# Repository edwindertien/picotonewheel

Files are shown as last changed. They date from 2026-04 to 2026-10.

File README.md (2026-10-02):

# Pico Tonewheel Organ

A Hammond-style tonewheel organ sound module built on a **Raspberry Pi Pico 2 (RP2350)**: nine-drawbar polyphonic tonewheel synthesis, percussion and key click, and an effects chain with **overdrive, vibrato, chorus and a stereo Leslie rotary-speaker simulation**. It plays from a home-built keyboard unit, from any USB MIDI controller plugged into its USB-A host socket, or from a computer. A small colour LCD shows the drawbars and effect settings.

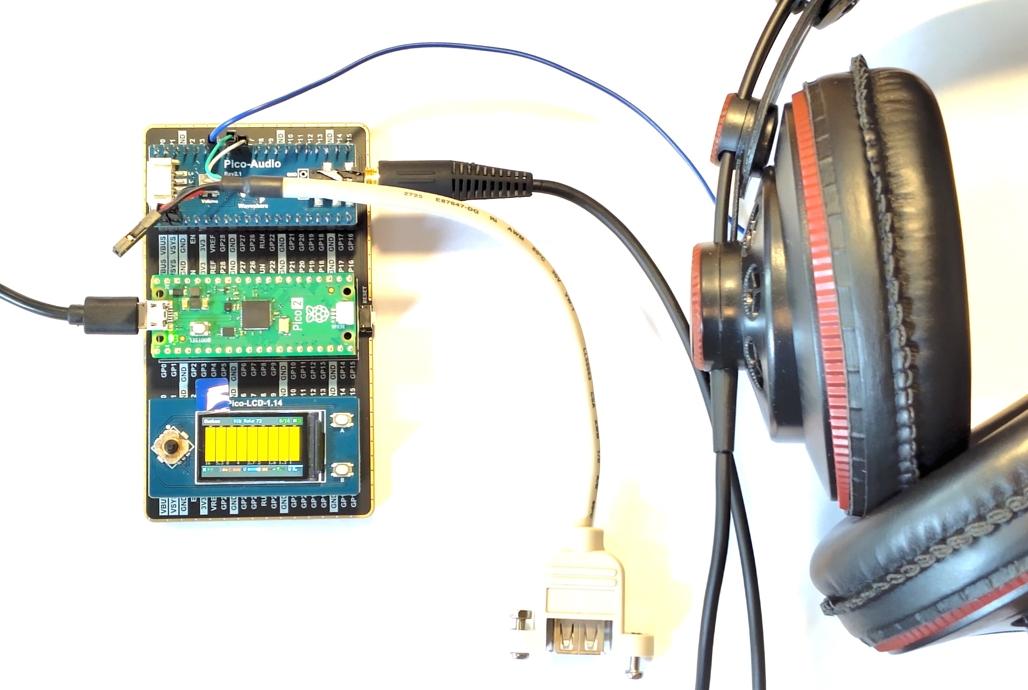
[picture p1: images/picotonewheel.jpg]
the module


> **TODO (author):** add 2–3 photos to `images/` — the finished instrument, the inside of the case, the front panel — and reference them here.

**Highlights**

- 16-note polyphony (9 partials per note) with Hammond drawbar footages, first-note-only percussion (2nd/3rd harmonic, fast/slow, soft/normal) and key click
- Overdrive: anti-aliased tube-style clipper with loudness-following makeup
- Vibrato (authentic ±0.25 semitone scanner depth), dual-quadrature chorus
- Leslie simulation: horn + drum rotors, Doppler, two microphones, **slow / stop / fast with realistic run-up and run-down**
- Three MIDI inputs merged: UART (keyboard unit), USB host (controllers), USB device (computer)
- A **load governor** that drops notes gracefully instead of letting the pitch fall or the DAC mute
- Everything controllable three ways: MIDI CC, joystick + LCD, serial console
- Runs from SRAM on core 1; I²S audio through a PIO state machine

## Contents

1. [The big picture](#1-the-big-picture)
2. [What you need](#2-what-you-need)
3. [Building the hardware](#3-building-the-hardware)
4. [Firmware: build, flash, first power-on](#4-firmware-build-flash-first-power-on)
5. [Playing it: controls](#5-playing-it-controls)
6. [How it works](#6-how-it-works)
7. [Tuning guide](#7-tuning-guide)
8. [Testing and verification status](#8-testing-and-verification-status)
9. [Troubleshooting](#9-troubleshooting)
10. [Limitations and roadmap](#10-limitations-and-roadmap)
11. [Repository layout, licence, credits](#11-repository-layout-licence-credits)

---

## 1. The big picture

system overview

The organ is two cooperating units:

| Unit | What it does | Where |
|---|---|---|
| **Keyboard & control unit** | Scans the keys, reads 16 analog controls (drawbars, pots, switches) and sends them as MIDI | companion project *pico MIDI keyboard* (RP2040 Pico) |
| **Tone generator** | Receives MIDI, synthesises and processes the sound, drives the DAC and the display | **this repository** (Pico 2) |

The tone generator accepts MIDI from **three sources at once** and treats them identically: the UART input (GP5, 31 250 baud — the keyboard unit), the USB-A host socket (one class-compliant USB MIDI device) and its native USB port (computer / DAW). Because everything is just MIDI, the sound module also works with nothing but a USB keyboard plugged in.

---

## 2. What you need

### 2.1 Tone generator (this repository)

| Qty | Part | Notes |
|-----|---|---|
| 1 | Raspberry Pi **Pico 2** (RP2350) | The build needs three PIO blocks and the Cortex-M33 FPU — a Pico 1 will not do |
| 1 | Waveshare **Pico-Audio** (Rev 2.1, CS4344 DAC) | stacks on the Pico; I²S pins are hard-wired on its PCB |
| 1 | Waveshare **Pico-LCD-1.14** (ST7789V 240×135, joystick, 2 buttons) | stacks on the Pico-Audio; pins hard-wired |
| 1 | USB-A socket (breakout or panel mount) | for the USB host input |
| 1 | 15 kΩ resistor | D+ pull-down — **required**, makes the Pico a USB host |
| 1 | Schottky diode (e.g. 1N5819) + 100 µF electrolytic + 100 nF ceramic | *recommended*: isolates power-hungry controllers (see [3.4](#34-power-and-noise)) |
| — | Hook-up wire, pin headers, USB cable for programming | |
| opt. | DIN-5 MIDI-in circuit (optocoupler 6N138 or similar) | feeds the same GP5 input; not part of the tested build |

> **TODO (author):** add supplier links / part numbers, the header arrangement used for the stack (or the expansion board mentioned below), power supply details (USB 5 V vs. VSYS) and the cost.
>
> The hardware note from the original README still applies: *the boards can be stacked, or used (for now) on an expansion board; a board combining MIDI-in and USB-host in is in the pipeline so the whole module can be a compact stack.*

### 2.2 Keyboard & control unit (companion project)

As built by the author (see the separate *pico MIDI keyboard* repository):

- Raspberry Pi Pico (RP2040), PlatformIO / earlephilhower core
- key matrix: 12 receive lines (GPIO0–11) and 16 send lines through two **74HC238** decoders (GPIO13/14/15 + 16); two selectable layouts — a double-row keyboard (two manuals) or velocity-sensing keys with make/break contacts
- **16 analog controls through a 4067 multiplexer** into ADC0 (GPIO26; mux select GPIO17/18/19/22): nine drawbars, three pots, three three-state switches, one Leslie switch
- MIDI out on UART TX (GPIO12 in the current firmware), 31 250 baud
- OLED + M5Stack encoder on I²C (GPIO20/21) for setup

> **TODO (author):** link the keyboard-unit repository, add its BOM, schematic and photos. Document the drawbar/pot/switch wiring (which mux channel is which CC).

### 2.3 Enclosure and panel

> **TODO (author) — everything needed to cut and assemble the case.** Suggested contents of a `hardware/` folder, each referenced from here:
>
> | File | Purpose |
> |------|---------|
> | `hardware/enclosure/*.svg` / `*.dxf` | laser-cut drawings, one file per material thickness |
> | `hardware/enclosure/README.md` | material (e.g. 3 mm birch ply / acrylic), kerf compensation used, assembly order, screws |
> | `hardware/panel/` | front-panel drawing with cut-outs: LCD window (Pico-LCD-1.14 active area), joystick + 2 buttons, USB-A socket, 3.5 mm audio jack, USB programming port access, MIDI in |
> | `hardware/bom.csv` | one machine-readable bill of materials |
> | `docs/photos/` | build photos in assembly order |
>
> A photo of the cut parts laid out, and one of the open case with the cabling, will save every builder an evening.

### 2.4 Tools

PlatformIO (VS Code extension or CLI), a soldering iron, a USB cable, and a serial terminal (the PlatformIO monitor works, 115 200 baud).

---

## 3. Building the hardware

### 3.1 The stack and the pins

```
[Pico-LCD-1.14]   ← top
[Pico-Audio]      ← middle   (pass-through header exposes all Pico pins)
[Pico 2]          ← bottom
```

GPIO map

Only **three connections are wired by hand**: GP5 (MIDI in), GP6/GP7 (USB host). Everything else is fixed by the two Waveshare boards, and there is **no conflict** between them.

| Function | GPIO |
|---|---|
| I²S: DIN / BCK / LRCK (Pico-Audio, hard-wired) | GP22 / GP26 / GP27 |
| LCD: DC, CS, SCK, MOSI, RST, backlight (SPI1) | GP8, GP9, GP10, GP11, GP12, GP13 |
| Joystick: UP, DOWN, LEFT, RIGHT, PRESS | GP2, GP18, GP16, GP20, GP3 |
| Buttons A, B | GP15, GP17 |
| MIDI in (UART1 RX) | GP5 |
| USB host D+, D− | GP6, GP7 |

### 3.2 USB host socket and UART link

wiring

1. **USB-A socket:** D+ → GP6, D− → GP7, GND → GND, VBUS → VSYS (pin 39) — preferably through the Schottky diode with the 100 µF + 100 nF capacitors on the socket side. **Fit the 15 kΩ resistor from GP6 to GND.** Without it the Pico never sees a device attach.
2. **MIDI link from the keyboard unit:** its UART TX → GP5, plus a common ground. Both boards are 3.3 V logic, so no optocoupler is needed between them.
3. Optional DIN-5 input: any standard MIDI-in optocoupler circuit can feed GP5.

> Pin order of the USB-A socket, looking into the socket: 1 VBUS (red), 2 D− (white), 3 D+ (green), 4 GND (black).

### 3.3 Programming the first time

Hold BOOTSEL while plugging the Pico 2 into the computer, then upload with PlatformIO (see section 4). Later uploads work without BOOTSEL.

### 3.4 Power and noise

A power-hungry controller on the USB host socket (the author observed it with an AKAI MPK mini; a small nanoKEY never caused it) can put **audible noise on the audio output** through the shared supply rail. The diode + capacitors in 3.2 prevent it. If you still hear noise, power the Pico from a clean 5 V supply rather than a laptop USB port.

> **TODO (author):** state how the module is powered in the finished case.

### 3.5 Suggested build photos

> **TODO (author):** the stack from the side; the USB-A socket wiring close-up; the MIDI link; the finished panel.

---

## 4. Firmware: build, flash, first power-on

### 4.1 Toolchain

- VS Code + PlatformIO (or the PlatformIO CLI)
- Platform: `https://github.com/maxgerhardt/platform-raspberrypi.git`, framework Arduino, **earlephilhower** core
- Libraries (fetched automatically): Adafruit TinyUSB, FortySevenEffects MIDI Library
- The PIO-based USB host library is **vendored** in `lib/pio_usb/` (Pico-PIO-USB v0.5.3 plus a small compatibility stub — see [section 9](#9-troubleshooting))

> **TODO (author):** pin the TinyUSB version that builds on your machine (`pio pkg list` shows it) in `platformio.ini`; the file currently tracks the latest release, which can change under you.

### 4.2 Environments

| Environment | Target | Clock | Notes |
|---|---|---|---|
| `pico2_tone` | Pico 2 | 240 MHz | **the full build**: USB host, effects, governor |
| `pico2_nohost` | Pico 2 | 200 MHz | no USB host (audio / MIDI-device testing) |
| `pico_tone` | Pico 1 | 133 MHz | **outdated** — see [limitations](#10-limitations-and-roadmap) |

240 MHz is used for the USB host build because it gives exact integer PIO clock divisors for USB full speed. The audio clock divisor is computed at run time from the real system clock, so pitch is unaffected.

```bash
pio run -e pico2_tone --target upload
pio device monitor            # 115200 baud
```

### 4.3 First power-on checklist

1. The LCD lights and shows the drawbars. A green square appears at the top right (audio load).
2. In the serial monitor: `help` lists the commands; `info` prints the organ state.
3. Plug in a USB MIDI keyboard — you should see `MIDI mounted idx=0 addr=1`, then `ON n=…` for each key.
4. Type `db 888000000` and play a note: a full gospel organ sound from both channels of the 3.5 mm output.
5. Type `perf` while holding a chord: the load split and polyphony limit appear.

---

## 5. Playing it: controls

### 5.1 The control panel and the MIDI CC map

front panel

| CC | Control | Range / behaviour |
|----|---|---|
| 12 – 20 | Drawbars 1–9 (16′ … 1′) | 0–127 → level 0–8 |
| 21 | Master volume | 0–127 |
| 22 | Overdrive | 0 = off, 1–127 = more |
| 23 | Chorus | one pot sets depth **and** mix together |
| 24 | Percussion switch | 2 = off · 62 = on, 2nd harmonic · 126 = on, 3rd harmonic |
| 25 | Vibrato switch | 2 = off · 62 = medium · 126 = high |
| 26 | Key-click switch | 2 = off · 62 = medium · 126 = high |
| 27 | **Leslie** switch | 2 = slow · 62 = stop · 126 = fast |
| 80 – 83 | Percussion detail | on/off · harmonic · decay (fast/slow) · level (soft/norm), each ≥ 64 = second option |
| 84 | Key-click level | 0–127 |
| 86 – 90 | Fine control | vibrato depth / rate · chorus depth / rate / mix |
| PC 0 – 3 | Program change | Full organ · Jazz · Flute · all off |

Three-state switches decode with thresholds at 32 and 94, so the values 2 / 62 / 126 (or anything near) work. The Leslie switch order can be swapped in `config.h` (`LESLIE_POS_*`). **Every received CC is printed on the serial console** — the quickest way to check what your own controller sends. By default all MIDI channels are accepted (`MIDI_CHANNEL 0` = OMNI).

### 5.2 Display and joystick

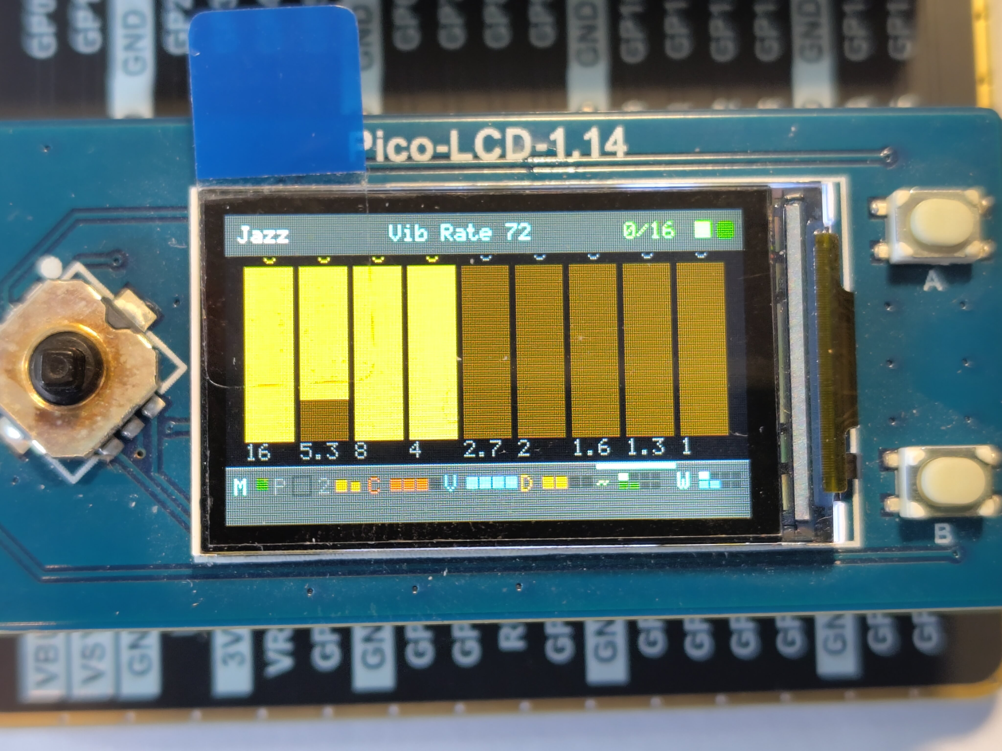
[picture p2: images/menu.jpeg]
menu photo


LCD layout

| Input | Action |
|---|---|
| Joystick LEFT / RIGHT | walk through: drawbars 1–9, click, volume, drive, vibrato depth / rate, chorus depth / rate / mix |
| Joystick UP / DOWN | change the selected value (drawbars ±1 level, others ±8). **Down pulls a drawbar down**, like a real one |
| Joystick PRESS | cycle presets: Full → Jazz → Flute |
| Button A | cycle the percussion settings |
| Button B | toggle key click |

Top bar: preset · selected parameter · **held notes / voice limit** (red when the governor is holding you back) · load square (green < 50 %, orange < 80 %, red) · MIDI dot.

### 5.3 Serial commands

115 200 baud, line-terminated.

| Command | Effect |
|---|---|
| `help`, `info`, `all` | command list · organ state · all notes off |
| `db 888000000` | set the nine drawbars (digits 0–8) |
| `pre full\|jazz\|flute\|off` | load a preset |
| `perc on\|off\|2\|3\|fast\|slow\|soft\|norm` | percussion |
| `click <0-127>`, `vol <0-127>` | key-click level, master volume |
| `drive <0-127>` | overdrive (0 = off) |
| `vib d <0-127>`, `vib r <0-127>` | vibrato depth, rate |
| `cho d\|r\|m\|a <0-127>` | chorus depth, rate, mix, **amount** (depth + mix together, like the pot) |
| `les stop\|slow\|fast` | Leslie speed |
| `perf` | audio load breakdown, polyphony limit, measured cost per oscillator |
| `pio` | audio PIO state |

---

## 6. How it works

### 6.1 Two cores

firmware processes

**Core 0** runs `loop()`: it polls the MIDI sources and the USB host, routes notes and CCs into the organ, handles the joystick, renders the LCD at 30 Hz and reads the serial console. **Core 1** runs only the audio loop, from SRAM: for each 256-sample buffer it computes one sample, pushes it into the PIO FIFO (paced by the DAC clock), and then lets the governor look at how long it all took.

The two cores share one global object, the organ. Core 0 takes its spinlock with `spin_lock_unsafe_blocking()`; core 1 only ever *tries* the lock, so it can never wait for core 0. Parameters are single bytes, so core 0 can write them without a lock.

Three rules came out of painful debugging and should not be broken (details in `context.md`):

1. **Never `spin_lock_blocking()`** — it disables interrupts, so USB MIDI packets get lost under chord bursts.
2. **Never compute a whole buffer and push it afterwards.** The PIO FIFO holds only a few samples; if it runs dry the I²S clocks stop and the CS4344 mutes.
3. **Audio code must run from SRAM and never block.** Everything on core 1 is force-inlined into `loop1()`, because code executed from flash competes with core 0 for the small XIP cache.

### 6.2 PIO allocation

PIO allocation

`audio_driver_init()` must run before `usb_host_init()` so the audio state machine claims PIO2 first and TinyUSB takes PIO0/PIO1.

### 6.3 The tonewheel engine

Each note is one **voice** with nine **partials**, one per drawbar:

| Drawbar | 1 | 2 | 3 | 4 | 5 | 6 | 7 | 8 | 9 |
|---|---|---|---|---|---|---|---|---|---|
| Footage | 16′ | 5⅓′ | 8′ | 4′ | 2⅔′ | 2′ | 1⅗′ | 1⅓′ | 1′ |
| Frequency × note | 0.5 | 1.5 | 1 | 2 | 3 | 4 | 5 | 6 | 8 |

A partial is a 32-bit phase accumulator reading a 4096-point sine table; its amplitude is `drawbar level / 8`. Only partials that actually sound (level > 0, below 22 kHz) are iterated, and the sum is scaled **once** for all voices. The inner loop is about 15 integer instructions per sounding partial.

- **Percussion** fires only on the first note of a new chord (authentic Hammond behaviour), at the 2nd or 3rd harmonic, fast or slow decay, soft or normal; while it is on, the 8′ drawbar is reduced by 25 % as on the original.
- **Key click** is a short noise burst on key press and release.
- **Vibrato** modulates the partials' phase increments with a sine LFO (0.5–9 Hz, depth up to ±0.25 semitone). The multiplier is applied once per 16 samples, in integer arithmetic, so there is no `powf()` and no per-oscillator float work in the audio path.

### 6.4 The effects chain

audio signal chain

Order: voices → percussion + click → **overdrive → chorus → Leslie** → master volume → clip → I²S. Each effect costs almost nothing when it is off (Leslie and overdrive bypass completely).

#### Overdrive

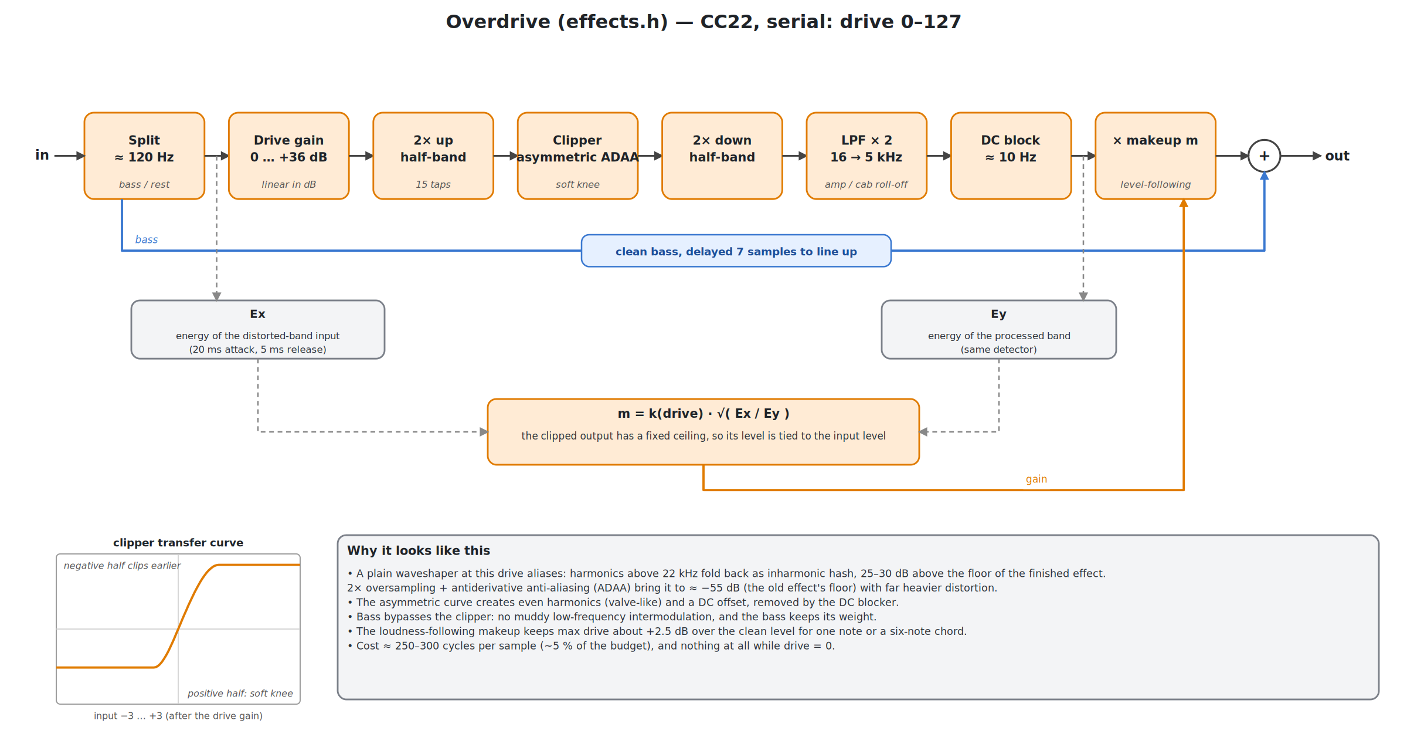
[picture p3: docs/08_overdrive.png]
overdrive


An asymmetric soft clipper (even + odd harmonics, valve-like) with gain from 0 to +36 dB. It had to be built carefully, because **a plain waveshaper at this drive aliases badly**: harmonics above 22 kHz fold back as inharmonic hash that sounds like noise. The shipped design uses 2× oversampling and antiderivative anti-aliasing, a gentle roll-off (16 kHz at low drive → 5 kHz at max) and a DC blocker, and keeps the **bass out of the clipper** so low notes stay clean. A loudness-following makeup keeps the level about **+2.5 dB over the clean signal at maximum drive** (set by `OD_LEVEL_DB`) for one note or a six-note chord alike.

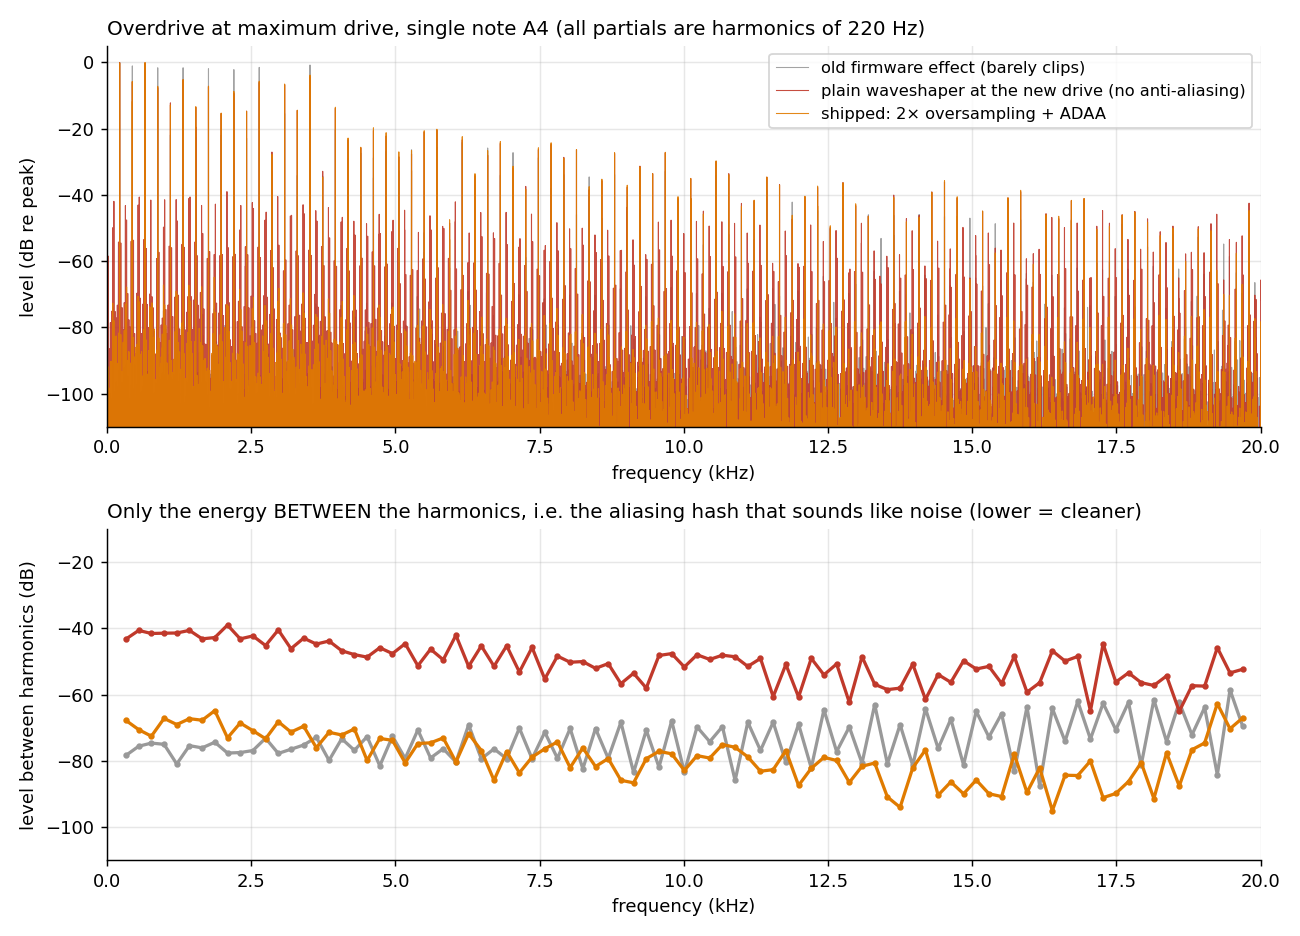
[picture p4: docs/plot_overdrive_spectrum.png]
overdrive spectrum


*Single note A4, maximum drive. Lower panel: only the energy between the harmonics (the aliasing hash). The shipped effect (orange) sits 25–30 dB below the plain waveshaper (red) and on the floor of the old, much milder effect (grey).*

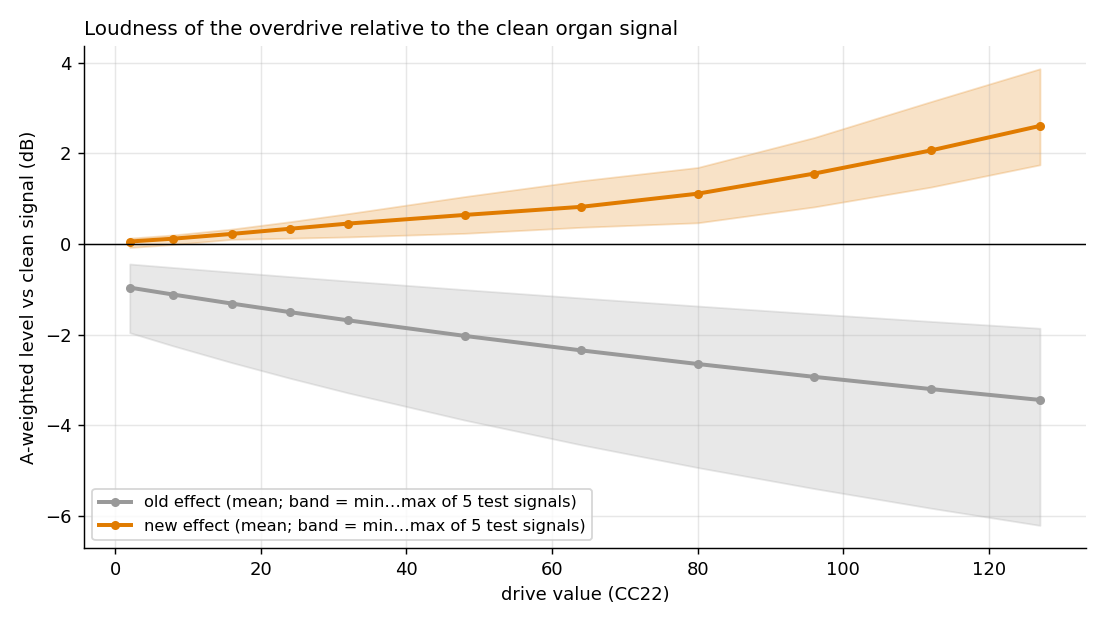
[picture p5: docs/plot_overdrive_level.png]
overdrive level


*Loudness relative to the clean organ signal across five test signals (one quiet note to a six-note full-drawbar chord). The old effect got quieter as drive increased; the new one rises smoothly and stays within about 2 dB across very different playing.*

Cost: roughly 250–300 cycles per sample (~5 % of the audio budget), paid only while drive > 0.

#### Chorus

Two delay lines (20 ms centre, up to ±2 ms swing, 0.2–3 Hz) driven by LFOs a quarter cycle apart — the Boss CE-2 arrangement. When one LFO reverses direction (the moment a single delay line clicks), the other is moving at its steadiest, so the artefact cancels. Depth and mix are independent; the panel pot sets both.

#### Leslie

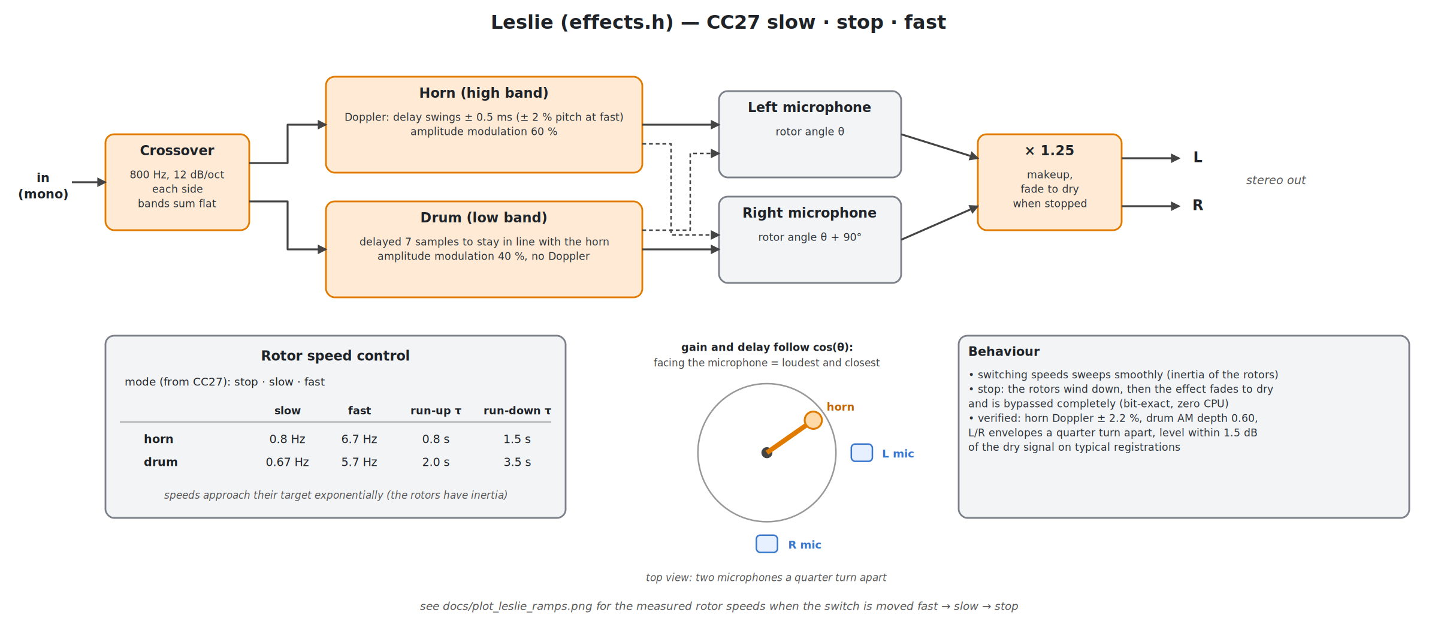
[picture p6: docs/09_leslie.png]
leslie


A crossover at 800 Hz splits the signal: the **horn** (highs) gets a modulated delay — the Doppler pitch shift, ±0.5 ms, about ±2 % pitch at full speed — plus 60 % amplitude modulation; the **drum** (lows) gets 40 % amplitude modulation. Two virtual microphones a quarter turn apart give a **stereo** output. Switching speeds does not jump: the rotors accelerate and decelerate exponentially with different inertia for horn and drum, exactly the "wind-up" you hear on a real cabinet. On "stop" the rotors wind down and the effect then fades to the dry signal and switches itself off completely.

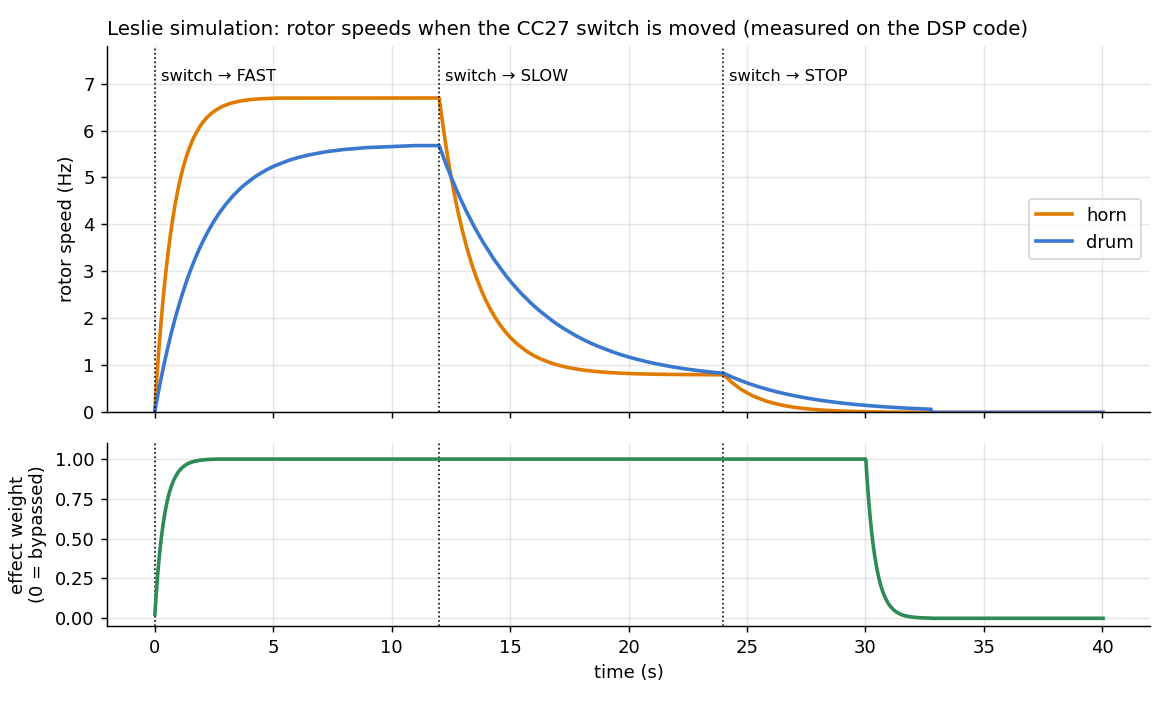
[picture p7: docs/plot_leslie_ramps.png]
leslie ramps


*Rotor speeds measured from the DSP code while the switch is moved fast → slow → stop.*

### 6.5 The load governor

governor

On a heavy chord with every effect on, the audio core can run out of time. Without protection the I²S clock stretches (the pitch falls) and finally the DAC loses lock and mutes. The governor prevents that: every buffer it measures what each oscillator really costs on this chip, works out how many notes fit under 80 % load, and lowers `voiceLimit` accordingly. Surplus notes **fade out over 5 ms, oldest first** — you lose notes, never pitch or sound. Switching effects on lowers the limit; switching them off gives the notes back, one per second. Run `perf` to see the numbers.

### 6.6 MIDI input and the USB host

All three sources call the same `midi_note_on / off / cc / program_change / pitch_bend` functions. The USB host (TinyUSB + PIO-USB, full speed) mounts **one** USB MIDI device; the callbacks must never block (no `_sync` TinyUSB calls), otherwise enumeration of other devices stalls. On disconnect all notes are released.

---

## 7. Tuning guide

Everything user-facing lives in `include/config.h`.

| Setting | Default | Effect |
|---|---|---|
| `MAX_ACTIVE_VOICES` | 16 | hard polyphony ceiling (the governor lowers it further when needed) |
| `GOV_TARGET_LOAD_PCT` | 80 | audio load the governor aims to stay under |
| `GOV_MIN_VOICES` | 3 | the governor never limits below this |
| `VOICE_FADE_SAMPLES` | 220 | fade-out length of a stolen note (~5 ms) |
| `VIBRATO_MAX_SEMITONES` | 0.25 | vibrato depth at maximum (0.25 = scanner vibrato; 0.5 = obvious) |
| `VIBRATO_SWITCH_MEDIUM / HIGH` | 64 / 127 | depth for the vibrato switch positions |
| `CLICK_LEVEL_MEDIUM / HIGH` | 40 / 110 | click levels for the click switch |
| `OD_MAX_GAIN_DB` | 36 | drive gain at maximum; higher adds little clipping but more aliasing |
| `OD_LEVEL_DB` | 2.5 | overdrive loudness at maximum relative to clean |
| `OD_GAIN_CURVE` | 1.0 | 1.0 = gain in dB linear with the pot; > 1 back-loads the effect |
| `OD_LPF_HIGH_HZ / LOW_HZ` | 16 k / 5 k | post-clipper roll-off at low / max drive |
| `LESLIE_*_HZ` | 0.8 / 6.7 · 0.67 / 5.7 | horn / drum speeds, slow / fast |
| `LESLIE_*_ACCEL_S / DECEL_S` | 0.8 / 1.5 · 2.0 / 3.5 | rotor run-up / run-down time constants |
| `LESLIE_HORN_DEPTH / DRUM_DEPTH` | 0.6 / 0.4 | amplitude-modulation depth |
| `LESLIE_STEREO` | 1 | 0 = both outputs identical (mono amp) |
| `LESLIE_POS_LOW / MID / HIGH` | slow / stop / fast | what each position of the CC27 switch selects |
| `CHORUS_MIX_DEFAULT` | 64 | default wet level |
| `MIDI_CHANNEL` | 0 | 0 = all channels, 1–16 = one channel |
| `ENABLE_LCD / SERIAL / USB_HOST / PERF` | 1 | feature switches |

If you change the overdrive clipper, filters or `OD_GAIN_CURVE`, the makeup calibration in `Overdrive::Overdrive()` has to be re-measured (the comment there explains how).

---

## 8. Testing and verification status

Being clear about what is verified how:

**Confirmed by the author on the hardware:** audio and MIDI from all three inputs; drawbars, percussion, click; vibrato, chorus, Leslie and overdrive sound and behave as intended; the load governor stops the pitch falling and the freezes at 6–7 notes.

**Verified on a PC against the real source (host test harness; see `context.md`):**

- CC mapping and switch decoding for the 2 / 62 / 126 values
- the voice engine against the previous one: identical within ±3 LSB (−74 dB); vibrato noise floor below −93 dB
- Leslie: bit-exact bypass when stopped, Doppler ±2.2 %, modulation depths, stereo phase, level within ~1.5 dB of dry
- overdrive: aliasing, loudness across five signals, click-free switching, pot sweeps, silence and extreme inputs
- governor: convergence and stability against synthetic cost models, graceful note fading

**Compiled for the Cortex-M33 and inspected:** the whole audio path is one call-free function; instruction counts per stage.

**Not yet measured on hardware:** the exact cycle costs. The numbers in this document are estimates from compiled instruction counts; the `perf` command gives the real ones.

> **TODO (author):** paste a few real `perf` outputs here (idle, 6 notes, 16 notes with all effects on) once measured.

---

## 9. Troubleshooting

| Symptom | Likely cause and fix |
|---|---|
| Pitch falls, or sound stops, with chords | The audio core is overloaded. Run `perf`; reduce effects or `MAX_ACTIVE_VOICES`; make sure you built the current firmware (governor) |
| No sound at all | Check the Pico-Audio is seated; run `pio` and confirm *SM enabled*; the DAC mutes if the clocks stop |
| USB keyboard not detected | 15 kΩ pull-down missing or on the wrong pin; **some controllers (AKAI MPK mini) only enumerate if plugged in before the Pico is powered** — power-cycle with the device attached |
| Noise on the output with a USB controller | Add the diode + capacitors from 3.2 |
| Two USB devices behind a hub: only one works | Known limitation of the vendored pio-usb v0.5.3 (see roadmap); use one device on the host socket and the keyboard unit on the UART |
| Only some drawbars respond | Your controller sends other CC numbers; watch the serial console (every CC is printed) and adjust `MIDI_CC_DRAWBAR_*` in `config.h` |
| Leslie "slow" and "fast" are swapped | swap `LESLIE_POS_LOW` and `LESLIE_POS_HIGH` |
| Compile error: conflicting declaration of `tuh_midi_*_cb` | TinyUSB callback signatures differ between versions; this code targets TinyUSB 3.7.x (`idx`-based callbacks) |
| Compile error: `pio_usb_host_endpoint_close` undefined | Keep the compatibility stub in `lib/pio_usb/` (declaration in `pio_usb.h`, body at the end of `pio_usb_host.c`) |
| Nothing in the serial monitor | `ENABLE_SERIAL` is 0, or the monitor is not at 115 200 baud |
| Serial output floods when a pot moves | Expected — each CC is printed |

---

## 10. Limitations and roadmap

- **One USB MIDI device on the host socket.** A hub works for one device; two devices behind a hub enumerate but only the first gets its MIDI interface. A newer Pico-PIO-USB (the one bundled with TinyUSB) is the likely fix.
- **`pico_tone` (Pico 1) is outdated.** The audio loop reads the Cortex-M33 cycle counter, which the RP2040 does not have; that environment would need the counter replaced (for example with `time_us_32()`) and a much lower voice count.
- **Velocity is ignored** (as on a Hammond).
- **Leslie is a model, not a measurement** of a particular cabinet; the speeds, depths and inertia are parameters you can tune. A hardware Leslie can still be fed from the audio output (set the switch to *stop* for a dry signal).
- Planned: a combined MIDI-in + USB-host board; further modules on the same platform (analog synth, FM synth, electric piano, drum machine — see `context.md`).

---

## 11. Repository layout, licence, credits

```
platformio.ini            build environments
README.md  context.md     this file · technical handoff for developers
images/                   photographs (module, menu)
docs/                     figures (SVG + PNG) and plots; docs/src/ regenerates the figures
include/
  config.h                all user-facing configuration and the CC map
  tonewheel_manager.h     voice pool, locks, effect chain order, load governor
  tonewheel_voice.h       one note = nine partials (the hot loop)
  effects.h               overdrive · vibrato · chorus · Leslie
  drawbars.h percussion.h click.h oscillator.h wavetable.h
  midi_handler.h          UART + USB-device MIDI
  usb_host.h              USB MIDI host (TinyUSB + PIO-USB callbacks)
  audio_driver.h  audio_pio.pio.h   I²S on PIO2
  perf.h                  cycle counter
  lcd.h lcd_driver.h lcd_buttons.h lcd_ui.h     display (UI in src/lcd.cpp)
  mclk.h voice.h voice_manager.h   unused / reference only
src/
  main.cpp                core 0 + core 1 entry points, MIDI callbacks, serial console
  lcd.cpp                 UI renderer and joystick handler
  audio_pio.pio           the I²S PIO program (Waveshare's)
lib/pio_usb/              vendored Pico-PIO-USB v0.5.3 + compatibility stub
```

> **TODO (author):** choose and add a licence (`LICENSE`); add `hardware/` as described in section 2.3.

**Credits:** [Pico-PIO-USB](https://github.com/sekigon-gonnoc/Pico-PIO-USB) (USB host in PIO), [TinyUSB / Adafruit TinyUSB](https://github.com/adafruit/Adafruit_TinyUSB_Arduino), the [Arduino MIDI Library](https://github.com/FortySevenEffects/arduino_midi_library), the [earlephilhower Arduino-Pico core](https://github.com/earlephilhower/arduino-pico), and the Waveshare PIO I²S program for the Pico-Audio board.

### Regenerating the figures

`docs/src/make_figures.py` draws every diagram (plain Python; PNG export needs `pip install cairosvg`):

```bash
cd docs/src && python3 make_figures.py          # writes ../*.svg and ../*.png
```

The three measured plots (`plot_*.png`) come from the host test harness described in `context.md` section 10 and are not produced by this script.

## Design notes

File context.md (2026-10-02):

# Project Context — Pico Tonewheel Organ (tone generator)

Technical handoff for developers and for new AI-assisted sessions. Read it together with `README.md`
(what it is and how to build it). This file is about **why it works the way it does and what will break if you change it.**

Status: all items below were confirmed working on the hardware by the author unless marked *(host-verified only)*.

---

## 1. What this is

Dual-unit Hammond-style organ. This repository is the **tone generator**: Raspberry Pi **Pico 2 (RP2350)**,
Waveshare Pico-Audio (CS4344, I²S) and Pico-LCD-1.14 (ST7789V). Input = MIDI from UART (GP5), USB host (GP6/GP7, one device)
and the native USB port. Companion: the *pico MIDI keyboard* unit (RP2040) that sends notes and CC12–27.

Toolchain: PlatformIO, `https://github.com/maxgerhardt/platform-raspberrypi.git`, earlephilhower core, Adafruit TinyUSB (3.7.x),
FortySevenEffects MIDI library, vendored Pico-PIO-USB v0.5.3 in `lib/pio_usb/`.

## 2. Current feature set

- 16-note (pool of 20) polyphonic tonewheel synthesis, 9 partials/note, drawbars, percussion (first-note-only), key click
- Effects chain: overdrive → chorus → **Leslie (stereo)**; vibrato inside the voices
- **Load governor** (adaptive polyphony with graceful fade-out) and `perf` console command
- Control by MIDI CC, joystick + LCD, serial console. CC map in section 6.
- USB MIDI host: **one** device (hub OK for one device)

## 3. Layout

```
platformio.ini            envs: pico2_tone (240 MHz, full) · pico2_nohost (200 MHz) · pico_tone (OUTDATED, see 9)
include/                  all headers (header-only DSP)
  config.h                every tunable + CC map + helper midi_switch3()
  tonewheel_manager.h     voice pool, spinlock, tick(), effect order, governor
  tonewheel_voice.h       one note: 9 partials, compact index list, tickRaw(), applyVibrato(), fade
  effects.h               Overdrive · Vibrato · Chorus · Leslie, _fx_sin()
  perf.h                  DWT cycle counter (raw registers, ARM-only; host stub)
  drawbars.h percussion.h click.h oscillator.h wavetable.h
  midi_handler.h usb_host.h audio_driver.h audio_pio.pio.h
  lcd*.h  (UI in src/lcd.cpp)     mclk.h voice.h voice_manager.h  = unused/reference
src/  main.cpp  lcd.cpp  audio_pio.pio
lib/pio_usb/              vendored + compatibility stub (section 8)
docs/                     figures; docs/src/make_figures.py regenerates them
```

## 4. Architecture

### 4.1 Cores and the shared organ
- **Core 0 `loop()`**: `midi_handler_poll` → `organ.serviceGovernor()` → `usb_host_poll` → `ui_handle_buttons` → LCD flush every 33 ms → `handleSerial` (1 char per pass). **No `delay()`** in `loop()`.
- **Core 1 `loop1()`** (`__not_in_flash_func`): per 256-sample buffer: for each sample `organ.tick(L,R)` then `audio_driver_put(L,R)` (interleaved), then `organ.governor(cycles, budget)`, then the LCD load value.
- One global `TonewheelManager organ`. Core 0 writes under `spin_lock_unsafe_blocking`; core 1 `spin_try_lock_unsafe` — it renders even if the lock is taken (worst case one slightly stale sample) and **never waits**.
- Parameters are `uint8_t`/enum single writes (atomic on ARM): no lock needed from core 0.

### 4.2 Hard rules (each cost hours; do not "simplify")
1. **Never `spin_lock_blocking()`** — disables interrupts → TinyUSB drops microframes → USB MIDI dies under chord bursts.
2. **Never double-pass audio** (compute buffer, then push). The PIO FIFO holds a few samples (~100–180 µs). A starved FIFO stops LRCK; the **CS4344 hardware-mutes** (shows up as noise whose pitch falls with load, then silence). Always interleave compute and put.
3. **Core 1 must not call**: `Serial`, LCD/SPI, LittleFS, NeoPixel `show()`. Core 1 must never block.
4. **Audio code runs from SRAM.** Only `loop1` was in RAM; everything it called was an ordinary function in *flash*, executed through the 16 KB XIP cache that core 0 (never idle) constantly evicts → large unpredictable stalls. Fix: `__attribute__((always_inline))` on `tick`, `Overdrive::process`, `Chorus::process`, `Leslie::process`, `tickRaw`, `_fx_sin`. Verify with `arm-none-eabi-g++ -S` that the audio path is one call-free function (currently ~1230 static instructions; calls only to cold `memset`/`sqrtf` error branches).
5. **Init order**: `audio_driver_init()` (claims PIO2) **before** `usb_host_init()` (TinyUSB takes PIO0 TX / PIO1 RX — 22 and 32 of 32 slots; PIO1 is exactly full).
6. **TinyUSB host callbacks must not make `_sync` calls** — blocks `USBHost.task()` and starves hub enumeration.
7. **No `float` in the per-oscillator path.** Hardware FPU is fine elsewhere, but the vibrato float convert/multiply per partial per sample was ~half the voice cost.
8. **DWT**: CMSIS `CoreDebug`/`DWT` are not exposed in arduino-pico. Use raw addresses `0xE000EDFC` (DEMCR bit 24), `0xE0001000` (CTRL bit 0), `0xE0001004` (CYCCNT). The DWT is **per core**: enable it on core 1.

### 4.3 PIO / clocks
RP2350 has 3 PIO blocks: PIO0 USB TX · PIO1 USB RX · PIO2 I²S (13 instr., the original Waveshare program, `.side_set 2`, **do not use the earlephilhower I²S library** — BCK/LRCK bit order is incompatible with the board wiring). 240 MHz gives exact PIO-USB divisors (TX ÷5, RX ÷2.5); the audio clkdiv is computed from `clock_get_hz()`.

## 5. DSP design notes

### 5.1 Voice engine (`tonewheel_voice.h`, `tonewheel_manager.h`)
- Partial = `{phase, inc, baseInc, amp, pad}` (16 bytes, one record per drawbar index) + compact list `_idx[]` of sounding partials (level>0, freq<22 kHz). `_idx` entries are always valid indices 0..8, so a racy read from core 1 can glitch one sample but never crash.
- `tickRaw()` returns the **unscaled** Σ(sine·amp); the manager applies `×559241 >> 32` (= ÷7680 = the old `>>8`, `/10`, `/3`). int32 headroom: 180 partials × 32767 × 256 < 2³¹.
- **Vibrato**: LFO runs every `VIBRATO_BLOCK`=16 samples; multiplier in **Q30** (`VIB_ONE = 1<<30`); `applyVibrato(q)` does `inc = baseInc·q >> 30` per sounding partial. New/retuned voices get the current state immediately (`setVibratoState`, `_updatePartials` re-applies). Q16 was *not* enough (phase error at high partials). Block-rate vs per-sample: same sound; noise floor below −93 dB.
- **Fade**: stolen voices fade over `VOICE_FADE_SAMPLES` (Q16 gain); `fading` voices are not "held" (`currentNote=255`, excluded from counts and from the duplicate-note check). A hard cut measured 24× the signal's own step (a click); the fade measures none.
- `_fx_sin(phase)` = parabola + refinement (error ≈ 0.001). **The previous polynomial was wrong at the ends of its range (±0.54 → a 1.08 step once per LFO cycle)** — this was the real cause of the long-chased "chorus loop-around click". Callers must pass phase ≥ −0.5 (truncation = floor).

### 5.2 Percussion / click
First-note-only trigger; 8′ drawbar −25 % while percussion is on; level tracks `drawbarSum`. Click level scale: CC84 → 0–255 internal; LCD/serial use 0–127 (a pre-existing inconsistency, harmless).

### 5.3 Chorus
Dual quadrature BBD: two 2048-sample delay lines, LFOs 90° apart (`sin`, `cos`), centre 20 ms, swing `depth·2/127` ms, rate 0.2–3 Hz, wet 0–50 % by `mix`. 5 ms swing (the first version) gave ±44 cents — far too much.

### 5.4 Overdrive (`Overdrive`, effects.h) — redesigned, measured
Signal path: split at 120 Hz (bass stays clean, delayed 7 samples) → gain 0…`OD_MAX_GAIN_DB` (linear in dB, `OD_GAIN_CURVE`=1.0) → **2× oversampling** (15-tap half-band, coefficients 0.313925991 / −0.093403660 / 0.044110376 / −0.026487629, polyphase, doubled ring buffers) → asymmetric cubic soft clipper (`c(u)=u−u³/3`, ±2/3; negative half `0.6·c(u/0.6)`) with **first-order ADAA** (antiderivative F, threshold |du|>2e-3 else midpoint) → half-band decimation → 2× one-pole LPF (16 kHz → 5 kHz with drive) → DC blocker (R=0.9986) → **loudness-following makeup** `m = k(drive)·√(Ex/Ey)` (detectors on the *distorted-band input* and the *processed band*, 20 ms attack / 5 ms release, updated every sample) → + clean bass. 10 ms on/off crossfade; parameters from a 128-entry table built in the constructor (no libm in the audio path).
- Why: a plain waveshaper at this drive **aliases at ≈ −30 dB** (inharmonic hash = "noise"); ADAA+2× brings it to ≈ −55 dB (ear-weighted ≈ −58…−61), the old effect's floor, with ~10 dB more distortion energy.
- Measured with: single note A4 (all partials harmonics of 220 Hz → anything between harmonics is aliasing), 5 test signals (1 quiet note … six-note full drawbars), A-weighted level vs clean.
- **Makeup calibration** (do it again if the clipper/filters/curve change): with 0 dB makeup the chain's A-weighted level vs clean was `0.089 − 1.163·s` dB, `s=(d/127)^1.3` (fit error ≤ 0.25 dB). So `k_dB = (OD_LEVEL_DB + 1.163)·s − 0.089`. Result: +0.1 dB at low drive → +2.6 dB at max (mean), all signals within ~2 dB.
- Rejected: updating the gain every 4 samples (sample-and-hold images → up to 7 dB worse aliasing at mid drive); gain > 36 dB (no extra clipping at max, more aliasing); fixed makeup (dense chords end up quieter than clean).
- Cost ≈ 250–300 cycles/sample, only while drive>0. Pitfalls seen: `1/g` compensation made it quieter; the asymmetric shaper alone leaves ~−100 LSB DC.

### 5.5 Leslie (`Leslie`, effects.h)
Crossover 800 Hz, **bilinear (TPT) one-poles**, 12 dB/oct each side, high band polarity-inverted so the bands sum to an allpass (exactly flat; the naive `high = x − low` leaked bass into the horn and a plain one-pole form drooped 1 dB at HF). Horn: delay swing ±`LESLIE_HORN_DOPPLER_MS`(0.5) (≈ ±2.2 % pitch at 6.7 Hz) + AM 60 %; drum: low band delayed 7 samples + AM 40 %. Two mics a quarter turn apart → stereo. `gain = (1−D/2) + (D/2)·cos θ`, `delay = base − A·cos θ`. Rotor speeds approach their targets exponentially (`ACCEL_S`/`DECEL_S` per rotor). Stop: when both rotors < `LESLIE_STOP_HZ`, the wet weight fades (0.4 s) and the effect **bypasses bit-exactly** (zero CPU). Makeup ×1.25 (level within ~1.5 dB of dry on typical registrations). Mode comes from `leslie.setSwitch(cc27)`; `LESLIE_POS_*` map the switch positions.

### 5.6 Load governor (`TonewheelManager::governor`, `serviceGovernor`)
Per 256-sample buffer on core 1: cycles in the voice loop vs. everything else → `_perOsc` (cycles/oscillator/sample) and `_rest` (cycles/sample), **rising fast (α 0.2), falling slowly (α 0.03)** (underestimating is the dangerous direction). Capacity = `(GOV_TARGET_LOAD_PCT%·budget − rest)/(perOsc·partialsPerNote)`, clamped to `[GOV_MIN_VOICES, MAX_ACTIVE_VOICES]`. `voiceLimit`: down at once; up +1 after `GOV_UP_BUFFERS` (~1 s) of spare capacity. **Emergency**: measured load > `GOV_EMERGENCY_PCT` → limit = held·target/load (proportional). Core 0 `serviceGovernor()` fades out held notes beyond the limit; `noteOn` steals the oldest held note the same way. Synthetic tests: converges in ~80 ms, no flapping, recovers; a heavy chord is overloaded for at most one buffer. `perf` prints the live numbers.
Context: before this, the engine (float vibrato on all partials, effects, everything in flash) overran at 6 notes (pitch −½ semitone) and froze at 7 (DAC mute).

## 6. MIDI map (config.h)

| CC | Meaning |
|----|---|
| 12–20 | drawbars 1–9 |
| 21 vol · 22 drive · 23 chorus amount (depth+mix) | pots |
| 24 percussion · 25 vibrato · 26 click | three-state: 2 / 62 / 126 → `midi_switch3()` thresholds 32 / 94 |
| 27 | Leslie: low=slow, mid=stop, high=fast (`LESLIE_POS_*`) |
| 80–84 | percussion on/off, harmonic, decay, level; 84 click level |
| 86–90 | vibrato depth/rate, chorus depth/rate/mix |
| PC 0–3 | Full / Jazz / Flute / off |
`MIDI_CC_VOLUME` was 7, then 10; it is now **21**. `MIDI_CC_DRIVE` was 85; now **22** (85 unused). The keyboard unit's 16 analog controls = CC12–27 exactly.
Dispatch order in `midi_cc()`: print everything → volume → `handleFxCC` → `handleCC` (drawbars/perc/click).

## 7. Serial commands
`help info all db pre perc click vol drive vib d|r cho d|r|m|a les stop|slow|fast perf pio`. Every received CC is printed.

## 8. USB host facts and compatibility stub
- Needs the **latest** Adafruit TinyUSB (host MIDI class `midi_host.*` does not exist in 3.4.x). Callbacks (3.7.x): `tuh_midi_mount_cb(idx, const tuh_midi_mount_cb_t*)`, `tuh_midi_umount_cb(idx)`, `tuh_midi_rx_cb(idx, xferred)`, `tuh_midi_tx_cb(idx, xferred)`, `tuh_midi_packet_read(idx, uint8_t[4])`.
- `hcd_pio_usb.c` (inside TinyUSB) calls `pio_usb_host_endpoint_close()`, absent in v0.5.3 → stub (declaration in `pio_usb.h`, body at the end of `pio_usb_host.c`).
- 15 kΩ pull-down on D+ (GP6) = host mode. One device works; **two devices behind a hub enumerate but only the first gets its MIDI interface** — cause not isolated (hub/deferred-attach path, probably the old pio-usb). To investigate: `-DCFG_TUSB_DEBUG=2` with `SERIAL_TUSB_DEBUG Serial`; likely fix: use the Pico-PIO-USB bundled inside TinyUSB.
- AKAI MPK mini: needs to be present at power-up; its current draw can put noise on the audio — diode + 100 µF + 100 nF.
- Do not call `_sync` descriptor functions in `tuh_mount_cb`.

## 9. Known issues / not done
- Two USB devices through a hub (above).
- **`pico_tone` (RP2040) env is stale**: `perf.h` reads the M33 DWT (hard fault on M0+).
- Exact cycle costs unmeasured on hardware; numbers in the docs are static instruction-count estimates. Use `perf`.
- Velocity ignored (intentional). Pitch bend supported.
- Open question for docs: pin the TinyUSB version in `platformio.ini`.

## 10. How the DSP was verified (host harness + cross-compiler)
Not in the repo (yet). Recreate: compile the real headers on a PC with `g++ -std=gnu++17` against tiny stubs — `Arduino.h` (min/max/Serial no-ops), `hardware/sync.h` (`spin_lock_*` no-ops), and `wavetable.h`'s `sineTable`. `perf.h` already has a host fallback. Tests that exist:
- **CC mapping** (2/62/126 for all switches, pots, no collision with CC12–20)
- **Voice-engine equivalence** old vs new, same event script: ±3 LSB (vibrato off); with the LFO held identically ±14 LSB (−69 dB)
- **Leslie**: ramp timing, bit-exact bypass, Doppler/AM depth, L/R correlation, level vs dry on real organ signals, click-free mode switching
- **Overdrive**: Python prototype (`scipy`) for design, C++ float32 matches it (aliasing −57.4 vs −57.7 dB); A-weighted loudness over 5 signals × drives; aliasing via the "harmonics of 220 Hz" trick; edge cases (on/off switching, pot sweep, silence, extreme input)
- **Governor / fade**: synthetic cost plants (pessimistic, optimised, effects toggled, wrong model), hard-cut vs fade click test
- **`main.cpp`** compiled on the host with stubs and driven through `handleSerial()` (one char per call!) and `midi_cc()`
- **Cross-compile** `arm-none-eabi-g++ -mcpu=cortex-m33 -mfloat-abi=softfp -mfpu=fpv5-sp-d16 -O2 -S` to inspect inlining, calls, loop instruction counts (oscillator loop ≈ 15 integer instructions; whole audio path one function).
Lessons: measure every "inaudible" optimisation (the 4-sample gain hold cost 5–7 dB of aliasing); a test must run the code the way the firmware does (e.g. `tick()` so fades finish).

## 11. Working agreement
Hardware-first, incremental: each change is tested on the instrument before the next. Deliver **only the changed files** (keeping `include/` vs `src/`); update README/context at verified breakpoints, not mid-debugging. When debugging goes in circles, revert to the last known-good state and rebuild incrementally. State uncertainty plainly.

## 12. Next ideas
- Companion keyboard unit: documentation + link in the README.
- Combined MIDI-in + USB-host board.
- Fix the hub / two-device case (newer pio-usb).
- Further modules on the same platform — **analog synth** (VCO/VCF/ADSR, Moog ladder: `s += g·(tanh(in) − tanh(s))` per stage; call `tanf` only on cutoff change), **FM**, **electric piano** (samples), **drum machine** (different main loop). Shared: `audio_driver.h`, `midi_handler.h`, `usb_host.h`, LCD drawing primitives, `oscillator.h`, `wavetable.h`, `perf.h`, the governor pattern and the effects (Leslie/chorus/overdrive are generic). Only voice engine, manager and UI differ.
- If CPU ever becomes limiting again: a **shared bank of 91 tonewheels** (fixed cost independent of the number of notes: per sample 91 table lookups + per-wheel weights updated on note on/off); it changes the partial tuning slightly to equal temperament and removes the need for voice stealing.

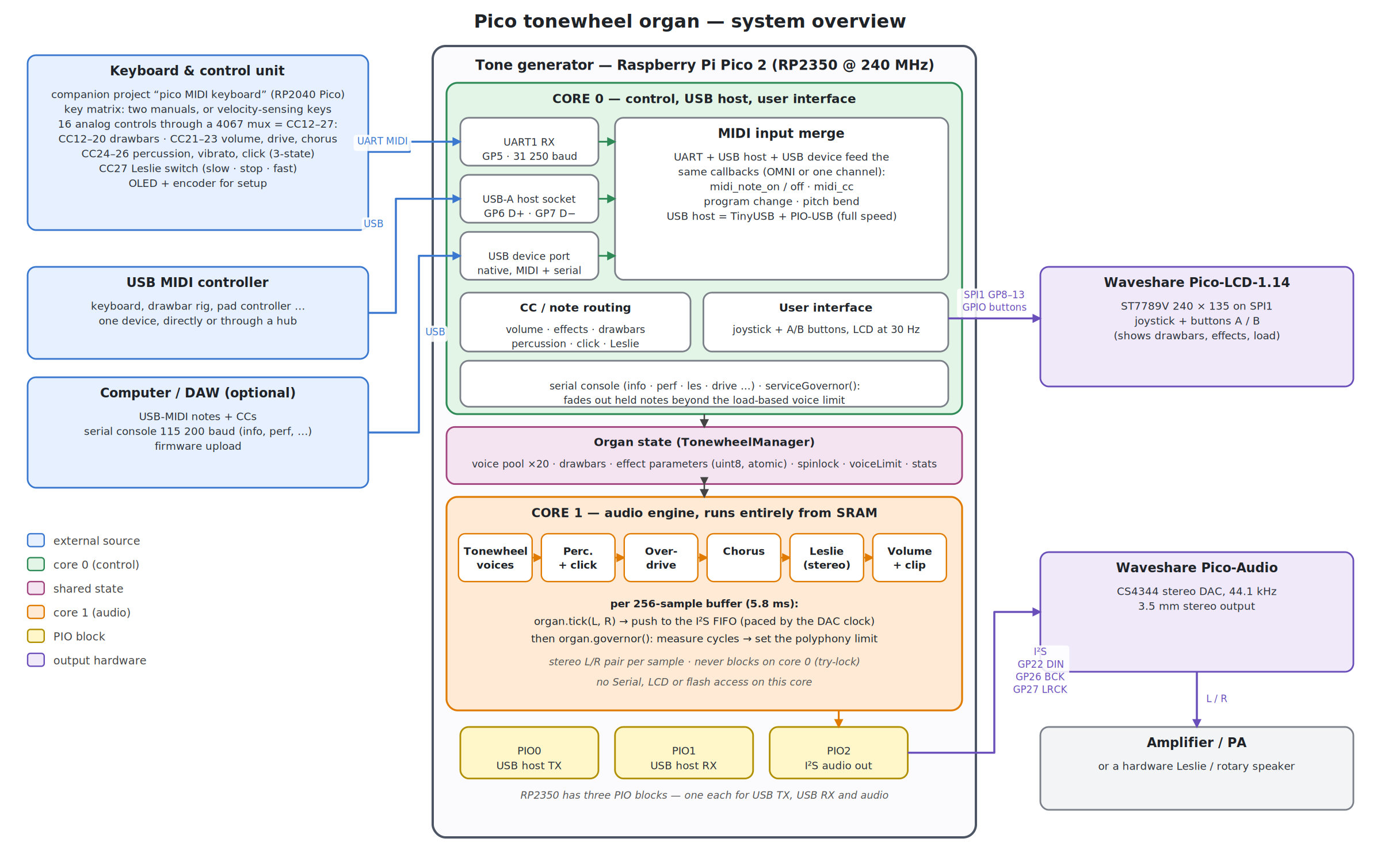
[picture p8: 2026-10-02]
docs/01_system_overview.png

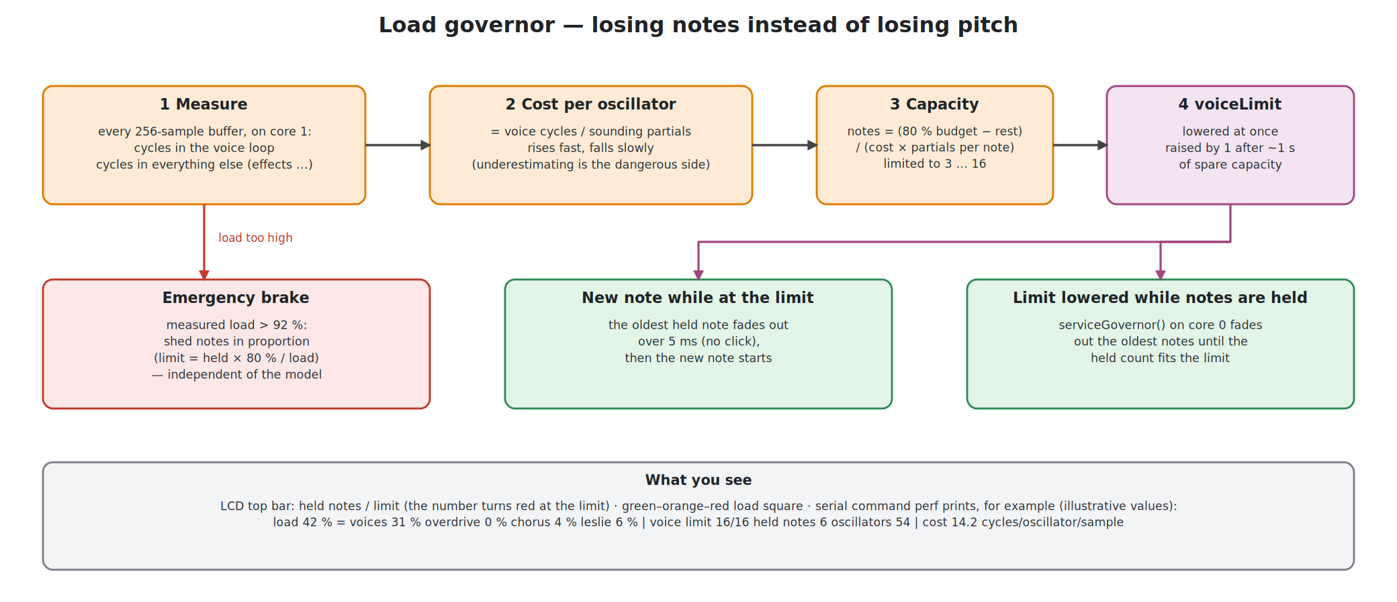
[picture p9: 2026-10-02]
docs/10_governor.png

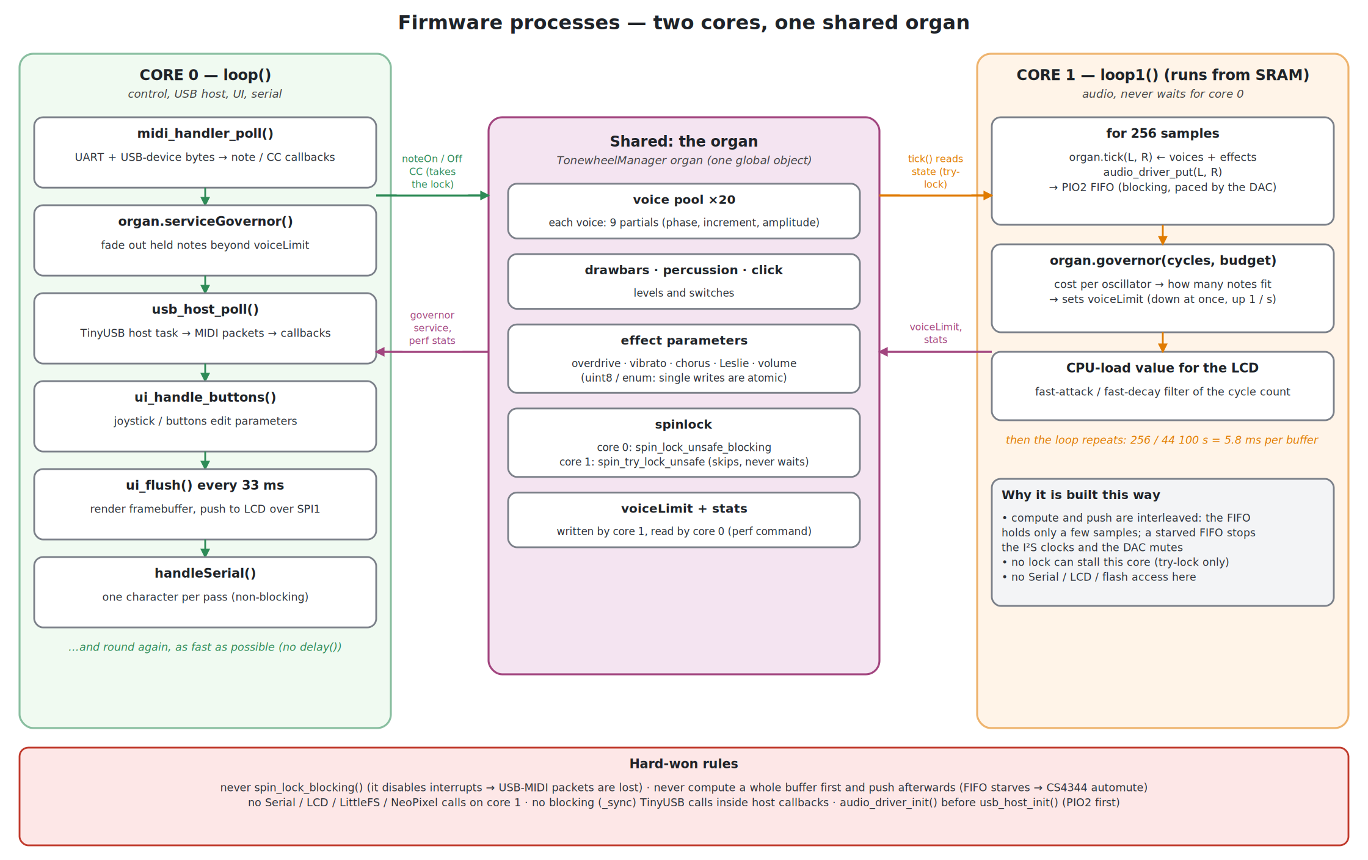
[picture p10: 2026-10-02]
docs/02_firmware_processes.png

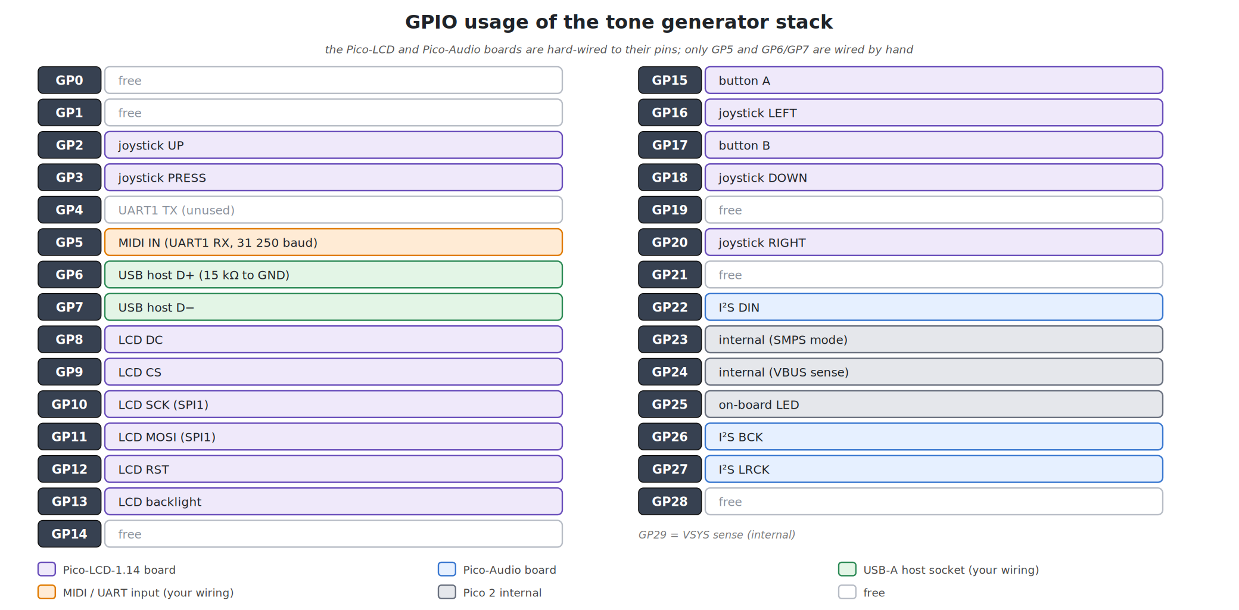
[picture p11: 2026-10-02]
docs/05_gpio_map.png

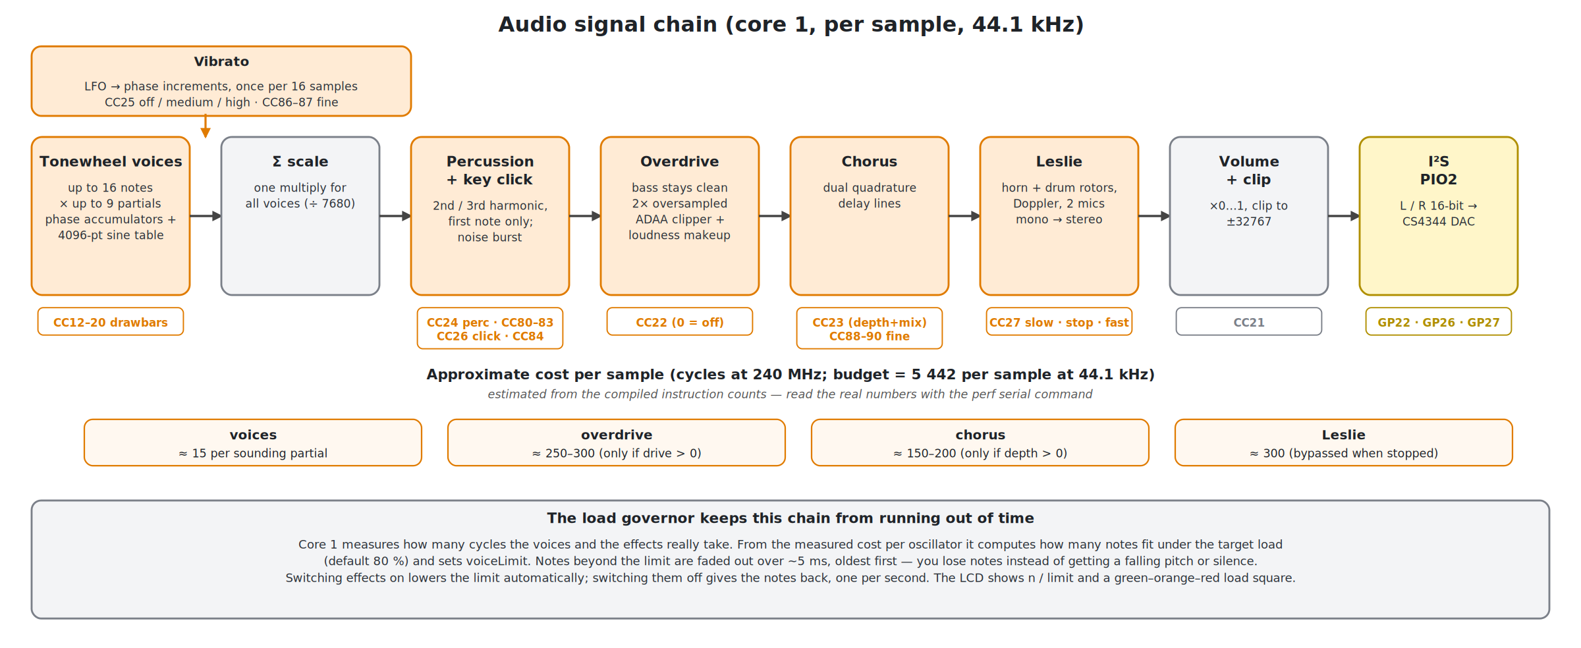
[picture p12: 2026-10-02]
docs/03_audio_signal_chain.png

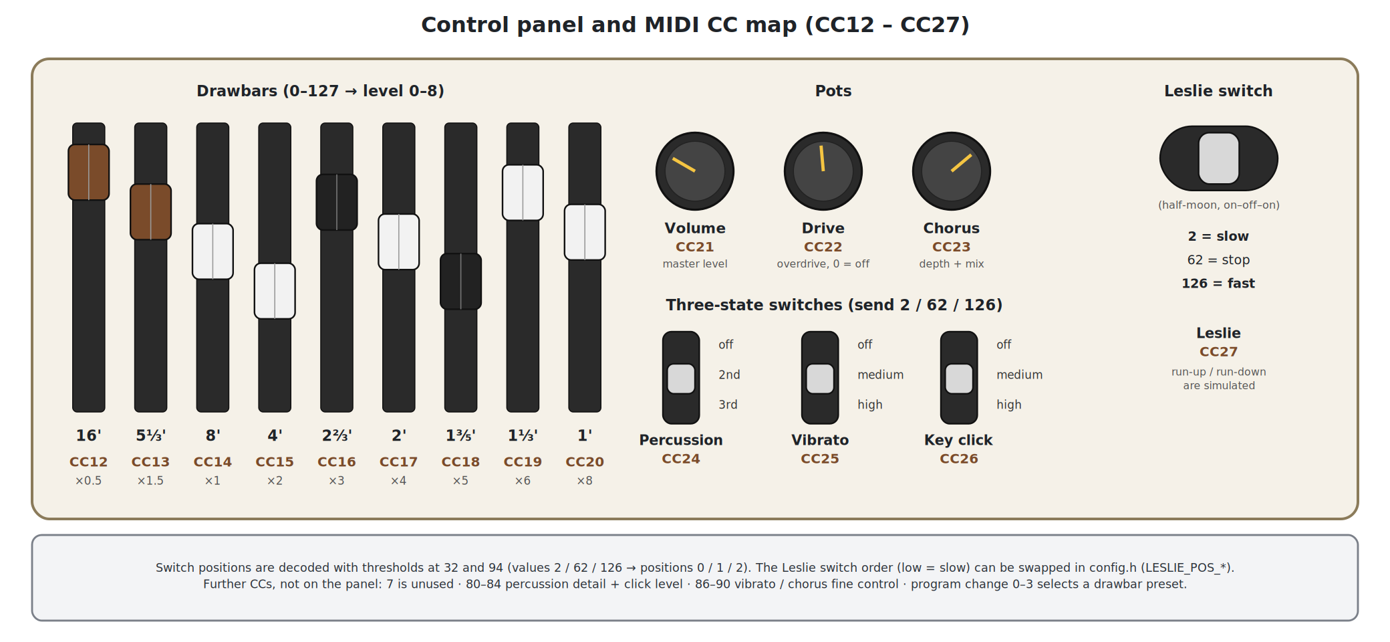
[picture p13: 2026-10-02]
docs/04_front_panel.png

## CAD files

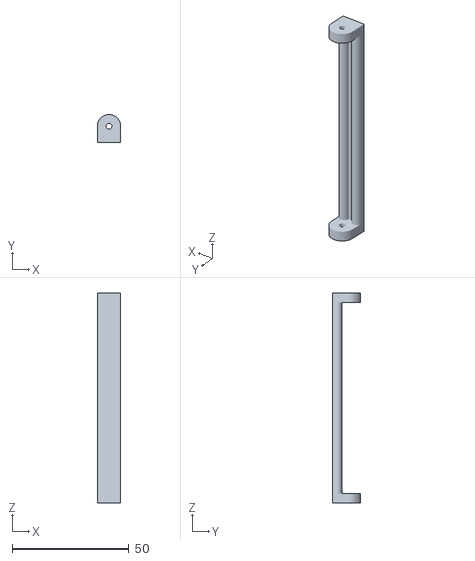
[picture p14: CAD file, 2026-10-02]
design/organ-panel-beam.stl
10.0 x 12.0 x 90.0

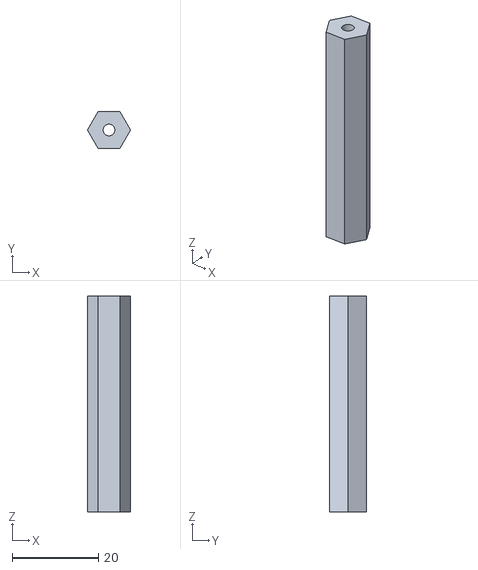
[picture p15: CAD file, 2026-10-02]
design/standof50.stl
10.0 x 8.66 x 50.0

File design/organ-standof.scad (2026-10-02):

$fn=40;

beam();

module beam(){{
    difference(){
    union(){
    translate([2,2,0])cylinder(d=4,h=90);
    translate([0,0,0])cube([10,2,90]);
        translate([8,2,0])cylinder(d=4,h=90);
    //translate([0,2,0])cube([2,8,90]);
        
    translate([5,7,0])cylinder(d=10,h=4);
    translate([0,2,0])cube([10,5,4]);
    //translate([2,2,0])cube([3,8,4]);
        

        
 //   translate([5,5,32])cylinder(d=10,h=32);
//    translate([2,2,32])cube([8,3,32]);
//    translate([2,2,32])cube([3,8,32]);    
        
    translate([5,7,86])cylinder(d=10,h=4);
    translate([0,2,86])cube([10,5,4]);  
        
    }
    translate([5,7,0])cylinder(d=2.5,h=10);
    translate([5,7,85])cylinder(d=2.5,h=10);
}
}
}

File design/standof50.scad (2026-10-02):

$fn = 50;

difference(){
    cylinder($fn = 6, d=10,h=50);
    cylinder(d=2.7,h=51);
}

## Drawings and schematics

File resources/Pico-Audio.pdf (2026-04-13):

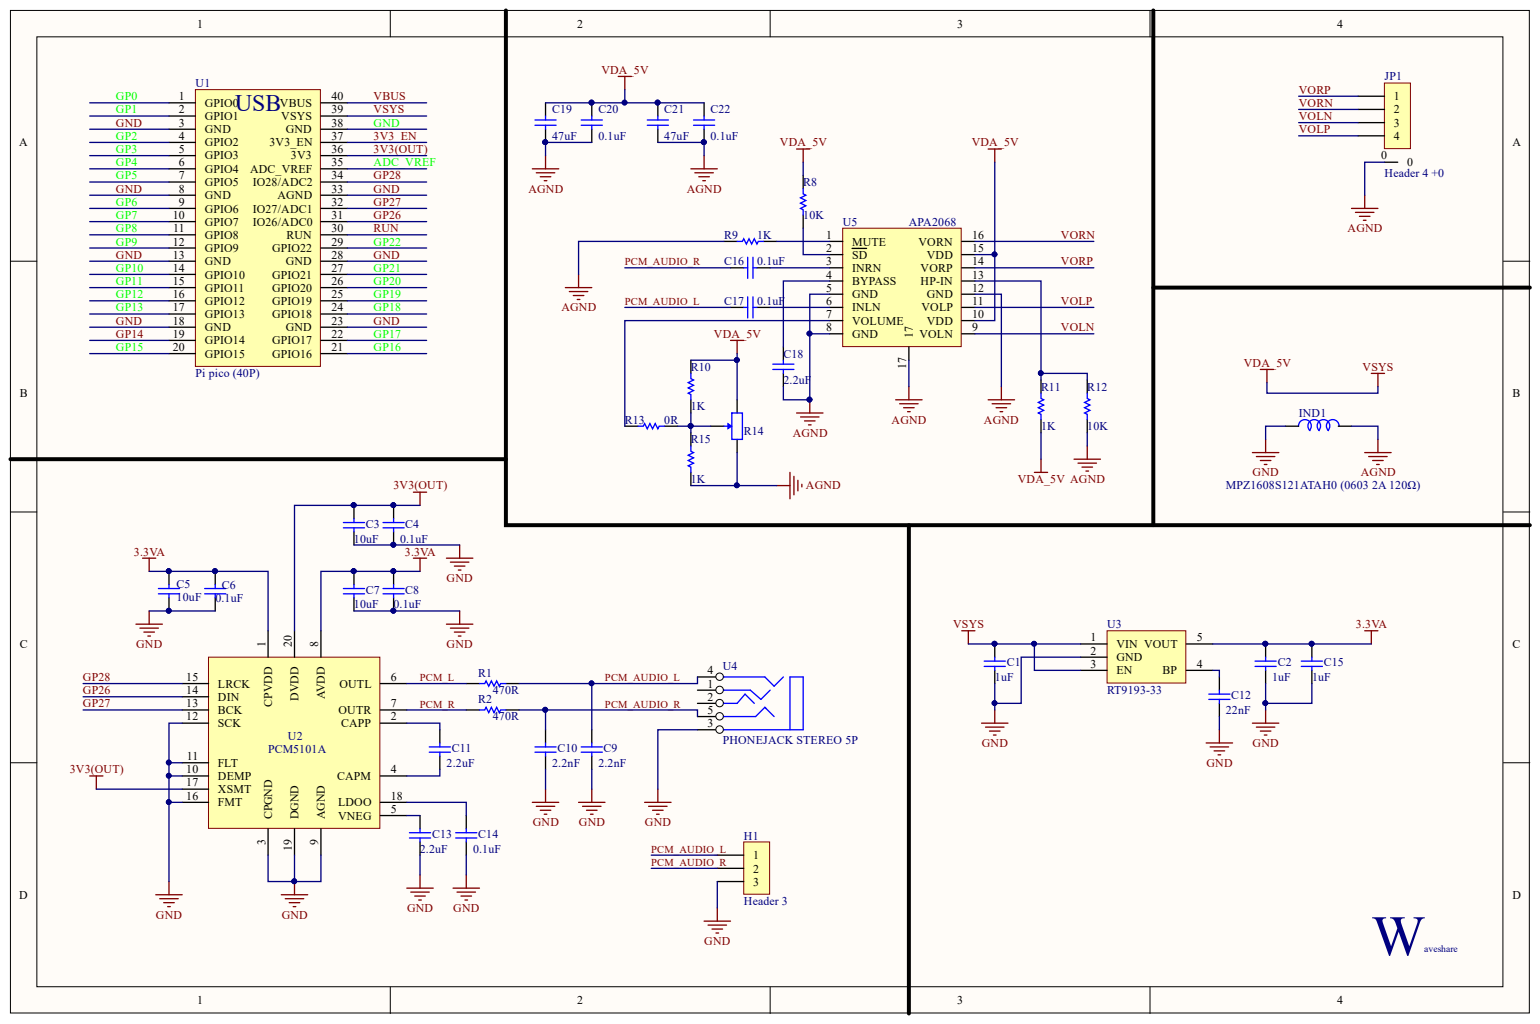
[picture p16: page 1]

GP0 GP1 GP2 GND GP3 GP4 GP5 GND GND GND GP6 GP7 GP8 GP9 GP10 GP11 GP12 GP13 GP15

5 | | 1 2
6 | | 1 1 1 0

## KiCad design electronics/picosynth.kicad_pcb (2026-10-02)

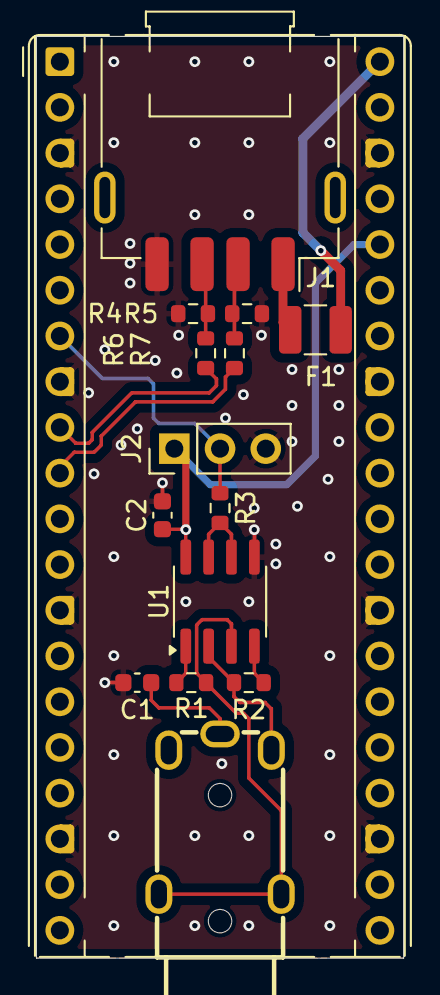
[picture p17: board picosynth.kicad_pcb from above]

Board: 2 copper layers, 20.4 x 51.2 mm, 15 parts (0 on the bottom side), 15 nets.

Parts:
A1: RaspberryPi_Pico; RaspberryPi_Pico_Common_THT
C1, C2: 100nF; C_0603_1608Metric
CN1: PJ-3220-Y; AUDIO-TH_PJ-3220-Y
F1: Yageo SMD1210B075TF; Fuse_1210_3225Metric
J1: USB_A; USB_A_Receptacle_GCT_USB1046
J2: Conn_01x03; PinHeader_1x03_P2.54mm_Vertical
R1, R2: 220R; R_0603_1608Metric
R3: 1k; R_0603_1608Metric
R4, R5: 15k; R_0603_1608Metric
R6, R7: 22R; R_0603_1608Metric
U1: HCPL-0631-500E; SOIC-8_3.9x4.9mm_P1.27mm

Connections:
+3.3V: A1.36 (3V3), C2.1, J2.1, U1.8 (VCC)
+5V: A1.40 (VBUS), F1.2
/MIDI_IN: A1.7 (GPIO5), J2.2, R3.1
/USBH_D+: A1.9 (GPIO6), R6.2
/USBH_D-: A1.10 (GPIO7), R7.2
/_MIDIIN1: CN1.4, R2.1, U1.2 (C1)
/_MIDIIN2: CN1.3, R1.1, U1.3 (C2)
GND: A1.3 (GND), A1.8 (GND), A1.13 (GND), A1.18 (GND), A1.23 (GND), A1.28 (GND), A1.38 (GND), C1.1, C2.2, J1.4 (GND), J2.3, R4.2, R5.2, U1.5 (GND)
unnamed: C1.2, CN1.1
unnamed: J1.3 (D+), R4.1, R6.1
unnamed: J1.2 (D-), R5.1, R7.1
unnamed: F1.1, J1.1 (VBUS)
unnamed: R1.2, U1.1 (A1)
unnamed: R2.2, U1.4 (A2)
unnamed: R3.2, U1.6 (VO2), U1.7 (VO1)

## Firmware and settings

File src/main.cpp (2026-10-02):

// ============================================================
//  main.cpp  —  Tonewheel organ  (v10 clean)
//
//  Audio engine: v7 (known-good, untouched)
//  Display:      Waveshare Pico-LCD-1.14 (optional, ENABLE_LCD)
//  Serial:       command interface (optional, ENABLE_SERIAL)
//
//  All config in config.h — MIDI CCs, channel, feature flags.
//
//  Core 0: MIDI + LCD + serial
//  Core 1: audio  (loop1 in SRAM via __not_in_flash_func)
// ============================================================

#include <Arduino.h>
#include "config.h"
#include "wavetable.h"
#include "oscillator.h"
#include "tonewheel_manager.h"
#include "perf.h"
#include "audio_driver.h"
#if ENABLE_LCD
#  include "lcd.h"
#endif
#include "midi_handler.h"
#if ENABLE_USB_HOST
#  include "usb_host.h"
#endif

int16_t sineTable[WAVETABLE_SIZE];
TonewheelManager organ;

#if ENABLE_SERIAL
static void handleSerial();
#endif

// ---- MIDI callbacks ----------------------------------------

void midi_note_on(uint8_t note, uint8_t velocity) {
#if MIDI_NOTE_PERC_TOGGLE >= 0
    if (note == MIDI_NOTE_PERC_TOGGLE) {
        organ.perc.enabled = !organ.perc.enabled;
        organ.propagateDrawbars();
#if ENABLE_LCD
        ui_mark_dirty_bottom();
#endif
        return;
    }
#endif
    organ.noteOn(note, velocity);
#if ENABLE_LCD
    ui_midi_activity();
    ui_mark_dirty_top();
#endif
#if ENABLE_SERIAL
    Serial.print("ON  n="); Serial.print(note);
    Serial.print(" ["); Serial.print(organ.activeCount()); Serial.println("]");
#endif
}

void midi_note_off(uint8_t note) {
#if MIDI_NOTE_PERC_TOGGLE >= 0
    if (note == MIDI_NOTE_PERC_TOGGLE) return;
#endif
    organ.noteOff(note);
#if ENABLE_LCD
    ui_mark_dirty_top();
#endif
#if ENABLE_SERIAL
    Serial.print("OFF n="); Serial.print(note);
    Serial.print(" ["); Serial.print(organ.activeCount()); Serial.println("]");
#endif
}

void midi_pitch_bend(int16_t bend) {
    organ.setPitchBend(bend);
}

void midi_cc(uint8_t cc, uint8_t value) {
#if ENABLE_SERIAL
    // Print ALL incoming CCs so unrecognised ones are visible
    Serial.print("CC "); Serial.print(cc);
    Serial.print("="); Serial.println(value);
#endif
    if (cc == MIDI_CC_VOLUME) {
        organ.masterVolume = (uint8_t)((uint16_t)value * 255 / 127);
#if ENABLE_LCD
        ui_mark_dirty_bottom();
#endif
        return;
    }
    if (organ.handleFxCC(cc, value)) {
#if ENABLE_LCD
        ui_mark_dirty_bottom();
#endif
        return;
    }
    if (organ.handleCC(cc, value)) {
#if ENABLE_LCD
        ui_mark_dirty_bars();
        ui_mark_dirty_bottom();
        ui_mark_dirty_top();
#endif
    }
}

void midi_program_change(uint8_t program) {
#if MIDI_PROGCHANGE_PRESETS
    switch (program % 4) {
        case 0: organ.drawbars.presetFullOrgan(); break;
        case 1: organ.drawbars.presetJazz();      break;
        case 2: organ.drawbars.presetFlute();     break;
        case 3: organ.drawbars.presetOff();       break;
    }
    organ.propagateDrawbars();
#if ENABLE_LCD
    ui_mark_all_dirty();
#endif
#if ENABLE_SERIAL
    Serial.print("PC "); Serial.println(program);
#endif
#endif
}

// ============================================================
//  Core 0  —  MIDI + display + serial
// ============================================================
void setup() {
    pinMode(LED_PIN, OUTPUT);
    digitalWrite(LED_PIN, LOW);

    midi_handler_init();

#if ENABLE_SERIAL
    Serial.begin(115200);
    // No while(!Serial) — starts without CDC connection
    delay(100);
    Serial.println("=== Tonewheel Organ ===");
    Serial.print("LCD:    "); Serial.println(ENABLE_LCD    ? "ON" : "OFF");
    Serial.print("MIDI ch:"); Serial.println(MIDI_CHANNEL == 0 ? " OMNI" : String(MIDI_CHANNEL));
#endif

    wavetable_init();
    organ.init();
    audio_driver_init(SAMPLE_RATE);  // claims PIO2 first

#if ENABLE_USB_HOST
    // USB host init AFTER audio — PIO2 already claimed,
    // so TinyUSB will use PIO0 (TX) and PIO1 (RX) as intended
    usb_host_init();
#if ENABLE_SERIAL
    Serial.print("USB host: ON  D+=GP"); Serial.print(MIDI_HOST_DP_PIN);
    Serial.print(" D-=GP"); Serial.println(MIDI_HOST_DP_PIN + 1);
#endif
#endif

#if ENABLE_LCD
    lcd_begin();
    ui_mark_all_dirty();
#endif

#if ENABLE_SERIAL
    Serial.println("Ready. Type 'help' for commands.");
#endif

    digitalWrite(LED_PIN, HIGH);
}

static uint32_t _last_ui_ms = 0;

void loop() {
    midi_handler_poll();
    organ.serviceGovernor();     // fade out held notes beyond the load-based voice limit

#if ENABLE_USB_HOST
    usb_host_poll();
#endif

#if ENABLE_LCD
    ui_handle_buttons(organ);
    uint32_t now = millis();
    if (now - _last_ui_ms >= 33) {
        ui_flush(organ);
        _last_ui_ms = now;
    }
#endif

#if ENABLE_SERIAL
    handleSerial();
#endif
    // No delay() here — keep loop() spinning fast so MIDI events
    // are processed with minimum latency. LCD updates are rate-limited
    // by the 33ms timer above; serial is non-blocking.
}

// ============================================================
//  Core 1  —  audio, runs from SRAM
// ============================================================
// CPU load: percentage of audio budget used by tick() computation.
// Written by core 1, read by core 0 for display. uint8_t write is atomic.
volatile uint8_t g_cpu_load_pct = 0;

void setup1() { delay(500); }

// Everything below is force-inlined into loop1() (see tick() / effects.h), and
// loop1() lives in SRAM, so the audio path never executes from flash.
void __not_in_flash_func(loop1)() {
    // Cycle budget for one buffer
    static constexpr uint32_t BUDGET_CY =
        (uint32_t)((uint64_t)F_CPU * BUFFER_FRAMES / SAMPLE_RATE);

    perf_enable();   // DWT is per core: enable on core 1 (idempotent)

    // Interleaved compute + put — the PIO FIFO must never starve (CS4344 automute).
    // Time only the tick() calls, not the blocking put().
    uint32_t total_cycles = 0;
    for (int i = 0; i < BUFFER_FRAMES; i++) {
        const uint32_t c0 = perf_now();
        int16_t sl, sr;
        organ.tick(sl, sr);
        total_cycles += perf_now() - c0;
        audio_driver_put(sl, sr);
    }

    // Load governor: caps polyphony so the load stays below GOV_TARGET_LOAD_PCT
    organ.governor(total_cycles, BUDGET_CY);

    // Display value: fast-attack, fast-decay IIR (x16 fixed point)
    const uint32_t load_now = (uint32_t)(((uint64_t)total_cycles * 100) / BUDGET_CY);
    static uint32_t load_filt16 = 0;
    const uint32_t target = load_now * 16;
    if (target > load_filt16)
        load_filt16 = (load_filt16 * 1 + target * 15) / 16;   // fast attack
    else
        load_filt16 = (load_filt16 * 13 + target * 3) / 16;   // fast decay
    g_cpu_load_pct = (uint8_t)((load_filt16 / 16) > 99 ? 99 : load_filt16 / 16);
}

// ============================================================
//  Serial commands
// ============================================================
#if ENABLE_SERIAL
static void handleSerial() {
    static String line = "";
    while (Serial.available()) {
        char c = (char)Serial.read();
        if (c != '\n' && c != '\r') { line += c; return; }
        line.trim();
        if (!line.length()) return;

        if (line == "help") {
            Serial.println("Commands:");
            Serial.println("  info              — organ state");
            Serial.println("  all               — all notes off");
            Serial.println("  db 888000000      — set drawbars (9 digits 0-8)");
            Serial.println("  pre full|jazz|flute|off");
            Serial.println("  perc on|off|2|3|fast|slow|soft|norm");
            Serial.println("  click <0-127>     — click level");
            Serial.println("  vol <0-127>       — master volume");
            Serial.println("  drive <0-127>     — overdrive (0=off)");
            Serial.println("  vib d <0-127>     — vibrato depth (0=off)");
            Serial.println("  vib r <0-127>     — vibrato rate");
            Serial.println("  cho d <0-127>     — chorus depth (0=off)");
            Serial.println("  cho r <0-127>     — chorus rate");
            Serial.println("  cho m <0-127>     — chorus wet/dry mix");
            Serial.println("  cho a <0-127>     — chorus amount (depth+mix together, like the pot)");
            Serial.println("  les stop|slow|fast — Leslie speed (run-up/down applies)");
            Serial.println("  perf              — audio load breakdown + polyphony limit");
            Serial.println("  pio               — audio PIO state");
        } else if (line == "info") {
            organ.debugPrint();
        } else if (line == "pio") {
            audio_driver_debug();
        } else if (line == "all") {
            organ.allNotesOff(); Serial.println("All notes off.");
        } else if (line.startsWith("db ") && line.length() == 12) {
            for (int i = 0; i < NUM_DRAWBARS; i++) {
                uint8_t v = line[3 + i] - '0';
                if (v <= 8) organ.drawbars.level[i] = v;
            }
            organ.propagateDrawbars();
#if ENABLE_LCD
            ui_mark_all_dirty();
#endif
            Serial.print("Drawbars: "); organ.drawbars.debugPrint();
        } else if (line=="pre full")  { organ.drawbars.presetFullOrgan(); organ.propagateDrawbars(); Serial.println("Full organ"); }
          else if (line=="pre jazz")  { organ.drawbars.presetJazz();      organ.propagateDrawbars(); Serial.println("Jazz"); }
          else if (line=="pre flute") { organ.drawbars.presetFlute();     organ.propagateDrawbars(); Serial.println("Flute"); }
          else if (line=="pre off")   { organ.drawbars.presetOff();       organ.propagateDrawbars(); Serial.println("All off"); }
          else if (line=="perc on")   { organ.perc.enabled=true;  organ.propagateDrawbars(); Serial.println("Perc ON"); }
          else if (line=="perc off")  { organ.perc.enabled=false; organ.propagateDrawbars(); Serial.println("Perc OFF"); }
          else if (line=="perc 2")    { organ.perc.thirdHarmonic=false; Serial.println("2nd"); }
          else if (line=="perc 3")    { organ.perc.thirdHarmonic=true;  Serial.println("3rd"); }
          else if (line=="perc fast") { organ.perc.fast=true;  Serial.println("Fast"); }
          else if (line=="perc slow") { organ.perc.fast=false; Serial.println("Slow"); }
          else if (line=="perc soft") { organ.perc.soft=true;  Serial.println("Soft"); }
          else if (line=="perc norm") { organ.perc.soft=false; Serial.println("Norm"); }
          else if (line.startsWith("click ")) {
            organ.click.level = constrain(line.substring(6).toInt(), 0, 127);
            Serial.print("Click: "); Serial.println(organ.click.level);
          } else if (line.startsWith("vol ")) {
            int v = constrain(line.substring(4).toInt(), 0, 127);
            organ.masterVolume = (uint8_t)((uint16_t)v * 255 / 127);
            Serial.print("Vol: "); Serial.println(v);
          } else if (line.startsWith("drive ")) {
            organ.overdrive.drive = constrain(line.substring(6).toInt(), 0, 127);
            Serial.print("Drive: "); Serial.println(organ.overdrive.drive);
          } else if (line.startsWith("vib d ")) {
            organ.vibrato.depth = constrain(line.substring(6).toInt(), 0, 127);
            Serial.print("Vib depth: "); Serial.println(organ.vibrato.depth);
          } else if (line.startsWith("vib r ")) {
            organ.vibrato.rate = constrain(line.substring(6).toInt(), 0, 127);
            Serial.print("Vib rate: "); Serial.println(organ.vibrato.rate);
          } else if (line.startsWith("cho d ")) {
            organ.chorus.depth = constrain(line.substring(6).toInt(), 0, 127);
            Serial.print("Chorus depth: "); Serial.println(organ.chorus.depth);
          } else if (line.startsWith("cho r ")) {
            organ.chorus.rate = constrain(line.substring(6).toInt(), 0, 127);
            Serial.print("Chorus rate: "); Serial.println(organ.chorus.rate);
          } else if (line.startsWith("cho m ")) {
            organ.chorus.mix = constrain(line.substring(6).toInt(), 0, 127);
            Serial.print("Chorus mix: "); Serial.println(organ.chorus.mix);
          } else if (line.startsWith("cho a ")) {
            int v = constrain(line.substring(6).toInt(), 0, 127);
            organ.chorus.depth = v; organ.chorus.mix = v;
            Serial.print("Chorus amount: "); Serial.println(v);
          } else if (line == "perf") {
            const TonewheelManager::Stats& st = organ.stats;
            Serial.print("load "); Serial.print(st.loadPct); Serial.print("%  =  voices ");
            Serial.print(st.voicesPct); Serial.print("%  overdrive ");
            Serial.print(st.odPct); Serial.print("%  chorus ");
            Serial.print(st.chorusPct); Serial.print("%  leslie ");
            Serial.print(st.leslieP); Serial.println("%  (rest = perc/click/vol/clip)");
            Serial.print("voice limit "); Serial.print(organ.voiceLimit);
            Serial.print("/"); Serial.print(MAX_ACTIVE_VOICES);
            Serial.print("   held notes "); Serial.print(organ.activeCount());
            Serial.print("   oscillators "); Serial.print(st.oscillators);
            Serial.print("   partials/note "); Serial.println(st.partialsPerNote);
            Serial.print("measured: "); Serial.print(st.perOscCycles / 10.0f, 1);
            Serial.print(" cycles/oscillator/sample, "); Serial.print(st.restCycles);
            Serial.println(" cycles/sample for everything else");
          } else if (line == "les stop") { organ.leslie.mode = 0; Serial.println("Leslie: stop");
          } else if (line == "les slow") { organ.leslie.mode = 1; Serial.println("Leslie: slow");
          } else if (line == "les fast") { organ.leslie.mode = 2; Serial.println("Leslie: fast");
          } else {
            Serial.print("Unknown: "); Serial.println(line);
          }

#if ENABLE_LCD
        ui_mark_dirty_bars(); ui_mark_dirty_bottom(); ui_mark_dirty_top();
#endif
        line = "";
    }
}
#endif

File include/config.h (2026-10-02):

#pragma once
#include <stdint.h>
// ============================================================
//  config.h  —  Pico 2 (RP2350) optimised build
//  Overclock: 200 MHz  |  Voices: 16  |  Wavetable: 4096 pts
// ============================================================

// ---- Feature flags -----------------------------------------
#define ENABLE_LCD        1
#define ENABLE_SERIAL     1
#define ENABLE_USB_HOST   1   // USB MIDI host on PIO0/PIO1 via Pico-PIO-USB
                              // Audio moved to PIO2 to avoid conflict
                              // Requires USB-A socket wired to GP6 (D+) and GP7 (D-)
                              // with 15kΩ pull-down on GP6, and 5V on VBUS

// ---- USB host pins -----------------------------------------
// D+ on GP6, D- automatically on GP7 (DP+1, DPDM pinout)
// These GPIO must be free — check pin conflict table in README
#define MIDI_HOST_DP_PIN  6

// ---- Polyphony ---------------------------------------------
// RP2350 @ 200 MHz with HW divide + FPU handles 16 comfortably.
// Raise to 20 if you overclock to 250 MHz.
#define MAX_ACTIVE_VOICES  16

// ---- MIDI --------------------------------------------------
#define MIDI_CHANNEL    0   // 0=OMNI

#define MIDI_CC_DRAWBAR_1   12
#define MIDI_CC_DRAWBAR_2   13
#define MIDI_CC_DRAWBAR_3   14
#define MIDI_CC_DRAWBAR_4   15
#define MIDI_CC_DRAWBAR_5   16
#define MIDI_CC_DRAWBAR_6   17
#define MIDI_CC_DRAWBAR_7   18
#define MIDI_CC_DRAWBAR_8   19
#define MIDI_CC_DRAWBAR_9   20

#define MIDI_CC_PERC_ONOFF      80
#define MIDI_CC_PERC_HARMONIC   81
#define MIDI_CC_PERC_DECAY      82
#define MIDI_CC_PERC_LEVEL      83
#define MIDI_CC_CLICK           84
#define MIDI_CC_VOLUME           21   // keyboard pot 1

#define MIDI_NOTE_PERC_TOGGLE   -1
#define MIDI_PROGCHANGE_PRESETS  1

// ---- I2S pins (Waveshare Pico-Audio Rev 2.1) ---------------
#define AUDIO_DATA_PIN        22
#define AUDIO_CLOCK_PIN_BASE  26

// ---- Audio -------------------------------------------------
#define SAMPLE_RATE    44100
#define BUFFER_FRAMES  256

// ---- Wavetable — 4096 points for Pico 2 -------------------
// SFDR improves from ~60 dB (1024 pts) to ~72 dB (4096 pts)
// Memory cost: 4096 × 2 = 8 KB (vs 2 KB) — trivial on 520 KB SRAM
#define WAVETABLE_BITS 12
#define WAVETABLE_SIZE (1 << WAVETABLE_BITS)   // 4096
#define PHASE_SHIFT    (32 - WAVETABLE_BITS)   // 20

// ---- Misc --------------------------------------------------
#define LED_PIN  25

// ---- Effects CC mapping ------------------------------------
// Overdrive
#define MIDI_CC_DRIVE           22   // keyboard pot 2: 0=off, 1–127=drive amount

// Vibrato
#define MIDI_CC_VIBRATO_DEPTH   86   // 0=off, 1–127=depth
#define MIDI_CC_VIBRATO_RATE    87   // 0..127=rate (0.5–9 Hz)
// Max vibrato depth in semitones at depth=127.
// Hammond vibrato is very subtle — 0.25 semitones is authentic.
// Increase for more dramatic effect (0.5 = noticeable, 1.0 = strong)
#define VIBRATO_MAX_SEMITONES   0.25f

// Chorus
#define MIDI_CC_CHORUS_DEPTH    88   // 0=off, 1–127=modulation depth
#define MIDI_CC_CHORUS_RATE     89   // 0..127=rate (0.2–3 Hz)
#define MIDI_CC_CHORUS_MIX      90   // 0..127=wet mix (0..50%)
#define CHORUS_MIX_DEFAULT      64   // default mix (~25% wet)

// ============================================================
//  Keyboard controls: 3 pots, 3 three-state switches, Leslie switch
// ============================================================
// Pots (continuous 0..127):
//   CC21 = master volume  (MIDI_CC_VOLUME above)
//   CC22 = overdrive      (MIDI_CC_DRIVE above)
#define MIDI_CC_CHORUS_AMOUNT   23   // keyboard pot 3: sets chorus depth AND mix together
                                     // (rate stays as set by CC89 / serial)

// Three-state switches send 2 / 62 / 126. Thresholds sit halfway between
// those values: <32 = position 0, <94 = position 1, otherwise position 2.
static inline uint8_t midi_switch3(uint8_t v) { return v < 32 ? 0 : (v < 94 ? 1 : 2); }

#define MIDI_CC_PERC_SWITCH     24   // 0 = off, 1 = on (2nd harmonic), 2 = on (3rd harmonic)
#define MIDI_CC_VIBRATO_SWITCH  25   // 0 = off, 1 = medium, 2 = high
#define MIDI_CC_CLICK_SWITCH    26   // 0 = off, 1 = medium, 2 = high

// Switch positions 1 and 2 → parameter values
#define VIBRATO_SWITCH_MEDIUM   64   // vibrato depth (0..127), see VIBRATO_MAX_SEMITONES
#define VIBRATO_SWITCH_HIGH     127
#define CLICK_LEVEL_MEDIUM      40   // click level (0..255 scale, same as CC84)
#define CLICK_LEVEL_HIGH        110

// ============================================================
//  Leslie (rotary speaker simulation, effects.h)
// ============================================================
#define MIDI_CC_LESLIE          27   // half-moon switch: slow / stop / fast
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

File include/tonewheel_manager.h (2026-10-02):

#pragma once
// ============================================================
//  tonewheel_manager.h  —  Pico 2 optimised
//
//  RP2350 Cortex-M33 has:
//    - Hardware divide  → plain / operator, no workarounds
//    - Hardware FPU     → float arithmetic essentially free
//    - 520 KB SRAM      → no memory pressure
//
//  vs Pico 1 version:
//    - No reciprocal-multiply approximations (just use /)
//    - Float percussion/click envelopes restored (FPU makes free)
//    - Spinlock + try-lock pattern retained (still dual-core)
//    - Polyphony cap from config.h (default 16)
// ============================================================

#include "tonewheel_voice.h"
#include "drawbars.h"
#include "percussion.h"
#include "click.h"
#include "effects.h"
#include "perf.h"
#include <hardware/sync.h>

#define MAX_TW_VOICES  20   // pool size — always >= MAX_ACTIVE_VOICES

class TonewheelManager {
public:
    Drawbars   drawbars;
    Percussion perc;
    Click      click;

    void init() {
        drawbars.init();
        perc.init();
        click.init();
        _cachedDbSum = 72;
        for (int i = 0; i < MAX_TW_VOICES; i++) {
            _voices[i].active      = false;
            _voices[i].currentNote = 255;
            _age[i]                = 0;
        }
        _clock       = 0;
        _activeCount = 0;
        voiceLimit   = MAX_ACTIVE_VOICES;
        _perOsc = 14.0f; _rest = 600.0f; _upCount = 0;
        _cycVoices = _cycOd = _cycChorus = _cycLeslie = 0;
        _lock = spin_lock_init(spin_lock_claim_unused(true));
    }

    void noteOn(uint8_t note, uint8_t velocity) {
        spin_lock_unsafe_blocking(_lock);
        for (int i = 0; i < MAX_TW_VOICES; i++) {
            if (_voices[i].currentNote == note) {      // fading voices have currentNote 255
                spin_unlock_unsafe(_lock); return;
            }
        }
        // Over the (dynamic) limit: fade out the oldest held notes to make room
        const uint8_t lim = voiceLimit;
        while (_countActive() >= lim) {
            int oldest = _findOldestActive();
            if (oldest < 0) break;
            _voices[oldest].startFade();
            _age[oldest] = 0;
        }
        int slot = _findFreeVoice();
        _voices[slot].setVibratoState(_vibQ);       // start already modulated
        _voices[slot].noteOn(note, velocity, drawbars);
        _age[slot]   = ++_clock;
        _activeCount = _countActive();
        spin_unlock_unsafe(_lock);

        perc.noteOn(note, _activeCount);
        click.trigger();
    }

    void noteOff(uint8_t note) {
        spin_lock_unsafe_blocking(_lock);
        for (int i = 0; i < MAX_TW_VOICES; i++) {
            if (_voices[i].currentNote == note) {
                _voices[i].noteOff(note);
                _age[i]      = 0;
                _activeCount = _countActive();
                spin_unlock_unsafe(_lock);
                click.trigger();
                perc.noteOff(_activeCount);
                return;
            }
        }
        spin_unlock_unsafe(_lock);
    }

    void setPitchBend(int16_t bend) {
        float st = bend / 8192.0f * 2.0f;
        spin_lock_unsafe_blocking(_lock);
        for (int i = 0; i < MAX_TW_VOICES; i++)
            _voices[i].setPitchBend(st, drawbars);
        spin_unlock_unsafe(_lock);
    }

    bool handleCC(uint8_t cc, uint8_t value) {
        if (drawbars.handleCC(cc, value)) {
            spin_lock_unsafe_blocking(_lock);
            _cachedDbSum = drawbars.drawbarSum();
            _propagate();
            spin_unlock_unsafe(_lock);
            return true;
        }
        if (perc.handleCC(cc, value)) {
            spin_lock_unsafe_blocking(_lock);
            _propagate();
            spin_unlock_unsafe(_lock);
            return true;
        }
        if (click.handleCC(cc, value)) return true;
        return false;
    }

    void propagateDrawbars() {
        spin_lock_unsafe_blocking(_lock);
        _cachedDbSum = drawbars.drawbarSum();
        _propagate();
        spin_unlock_unsafe(_lock);
    }

    uint8_t masterVolume = 255;   // 0–255, set via serial 'vol' or MIDI_CC_VOLUME

    // ---- Effects -------------------------------------------
    Overdrive overdrive;
    Vibrato   vibrato;
    Chorus    chorus;
    Leslie    leslie;

    // Handle effects CCs — returns true if consumed
    bool handleFxCC(uint8_t cc, uint8_t value) {
        switch (cc) {
            case MIDI_CC_DRIVE:          overdrive.drive   = value; return true;
            case MIDI_CC_CHORUS_AMOUNT:  chorus.depth = value; chorus.mix = value; return true;
            case MIDI_CC_LESLIE:         leslie.setSwitch(value);   return true;
            case MIDI_CC_VIBRATO_SWITCH:
                switch (midi_switch3(value)) {
                    case 0:  vibrato.depth = 0;                       break;
                    case 1:  vibrato.depth = VIBRATO_SWITCH_MEDIUM;   break;
                    default: vibrato.depth = VIBRATO_SWITCH_HIGH;     break;
                }
                return true;
            case MIDI_CC_VIBRATO_DEPTH:  vibrato.depth     = value; return true;
            case MIDI_CC_VIBRATO_RATE:   vibrato.rate      = value; return true;
            case MIDI_CC_CHORUS_DEPTH:   chorus.depth      = value; return true;
            case MIDI_CC_CHORUS_RATE:    chorus.rate       = value; return true;
            case MIDI_CC_CHORUS_MIX:     chorus.mix        = value; return true;
            default: return false;
        }
    }

    // ---- Audio hot path — core 1 ----------------------------
    // Stereo: the Leslie produces two "microphone" signals.
    // With the Leslie stopped both channels carry the same mono signal.
    // Force-inlined into loop1() so the whole path runs from SRAM.
    __attribute__((always_inline)) inline void tick(int16_t& left, int16_t& right) {
        // 1. Vibrato: LFO + per-voice phase increments, once per VIBRATO_BLOCK samples
        if (--_vibCount <= 0) {
            _vibCount = VIBRATO_BLOCK;
            vibrato.tick(VIBRATO_BLOCK);
            const uint32_t q = (uint32_t)(vibrato.pitchMult * (float)VIB_ONE + 0.5f);
            if (q != _vibQ) {
                _vibQ = q;
                for (int i = 0; i < MAX_TW_VOICES; i++)
                    if (_voices[i].active) _voices[i].applyVibrato(q);
            }
        }
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

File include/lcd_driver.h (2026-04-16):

#pragma once
// ============================================================
//  lcd_driver.h  –  Waveshare Pico-LCD-1.14 low-level driver
//
//  ST7789V, 240x135, RGB565, SPI1
//  Pins (hard-wired on board):
//    GP10 = SCK    GP11 = MOSI   GP9  = CS
//    GP8  = DC     GP12 = RST    GP13 = BL
//
//  Uses a 240×TILE_H tile buffer (9.6 KB) for partial updates.
//  Full screen = 8 tiles; individual regions can be refreshed
//  cheaply by only pushing dirty tiles.
// ============================================================

#include <Arduino.h>
#include <SPI.h>
#include <hardware/gpio.h>

// ---- Pins --------------------------------------------------
#define LCD_SCK   10
#define LCD_MOSI  11
#define LCD_CS     9
#define LCD_DC     8
#define LCD_RST   12
#define LCD_BL    13

// ---- Screen dimensions ------------------------------------
#define LCD_W   240
#define LCD_H   135

// ---- Tile buffer -------------------------------------------
#define TILE_H   20           // rows per tile
#define TILE_BUF_BYTES  (LCD_W * TILE_H * 2)
static uint16_t _tile_buf[LCD_W * TILE_H];

// ---- RGB565 colour helpers ---------------------------------
#define RGB565(r,g,b) ((uint16_t)(((r & 0xF8) << 8) | ((g & 0xFC) << 3) | (b >> 3)))

// Colour palette
#define COL_BLACK    RGB565(  0,   0,   0)
#define COL_WHITE    RGB565(255, 255, 255)
#define COL_AMBER    RGB565(255, 160,   0)   // drawbar active
#define COL_AMBER_DIM RGB565( 60,  38,   0)  // drawbar empty
#define COL_GREEN    RGB565(  0, 200,  60)   // MIDI activity
#define COL_ORANGE   RGB565(255,  80,   0)   // percussion
#define COL_BLUE     RGB565( 40, 120, 255)   // volume
#define COL_GRAY     RGB565( 80,  80,  80)   // labels
#define COL_DARKGRAY RGB565( 30,  30,  30)   // backgrounds
#define COL_RED      RGB565(220,  40,  40)   // click

// ---- SPI helper --------------------------------------------
static SPISettings _lcd_spi_settings(62500000, MSBFIRST, SPI_MODE0);

inline void _lcd_cmd(uint8_t cmd) {
    digitalWrite(LCD_DC, LOW);
    digitalWrite(LCD_CS, LOW);
    SPI1.transfer(cmd);
    digitalWrite(LCD_CS, HIGH);
}

inline void _lcd_data8(uint8_t d) {
    digitalWrite(LCD_DC, HIGH);
    digitalWrite(LCD_CS, LOW);
    SPI1.transfer(d);
    digitalWrite(LCD_CS, HIGH);
}

inline void _lcd_data16(uint16_t d) {
    digitalWrite(LCD_DC, HIGH);
    digitalWrite(LCD_CS, LOW);
    SPI1.transfer16(d);
    digitalWrite(LCD_CS, HIGH);
}

// ---- Set address window ------------------------------------
inline void _lcd_set_window(uint16_t x0, uint16_t y0, uint16_t x1, uint16_t y1) {
    // ST7789 on this board has x offset=0, y offset=0 for landscape
    _lcd_cmd(0x2A);
    digitalWrite(LCD_DC, HIGH); digitalWrite(LCD_CS, LOW);
    SPI1.transfer(x0 >> 8); SPI1.transfer(x0 & 0xFF);
    SPI1.transfer(x1 >> 8); SPI1.transfer(x1 & 0xFF);
    digitalWrite(LCD_CS, HIGH);
    _lcd_cmd(0x2B);
    digitalWrite(LCD_DC, HIGH); digitalWrite(LCD_CS, LOW);
    SPI1.transfer(y0 >> 8); SPI1.transfer(y0 & 0xFF);
    SPI1.transfer(y1 >> 8); SPI1.transfer(y1 & 0xFF);
    digitalWrite(LCD_CS, HIGH);
    _lcd_cmd(0x2C);
}

// ---- Push tile buffer to screen ----------------------------
// Pushes TILE_H rows starting at y_start
inline void lcd_push_tile(uint16_t y_start) {
    uint16_t y_end = y_start + TILE_H - 1;
    if (y_end >= LCD_H) y_end = LCD_H - 1;
    _lcd_set_window(0, y_start, LCD_W - 1, y_end);
    digitalWrite(LCD_DC, HIGH);
    digitalWrite(LCD_CS, LOW);
    // Transfer as bytes (big-endian swap needed: RGB565 high byte first)
    uint32_t n = (uint32_t)(y_end - y_start + 1) * LCD_W;
    for (uint32_t i = 0; i < n; i++) {
        uint16_t px = _tile_buf[i];
        SPI1.transfer(px >> 8);
        SPI1.transfer(px & 0xFF);
    }
    digitalWrite(LCD_CS, HIGH);
}

// ---- Tile buffer pixel write -------------------------------
inline void tile_pixel(uint16_t x, uint16_t tile_y, uint16_t colour) {
    _tile_buf[tile_y * LCD_W + x] = colour;
}

// Fill a rect in the tile buffer (tile_y is local y within tile)
inline void tile_fill_rect(uint16_t x, uint16_t tile_y, uint16_t w, uint16_t h, uint16_t colour) {
    for (uint16_t row = tile_y; row < tile_y + h; row++) {
        for (uint16_t col = x; col < x + w; col++) {
            _tile_buf[row * LCD_W + col] = colour;
        }
    }
}

// Draw a single char (5x7 font, scaled) into tile buffer
// Only supports printable ASCII 32-127
// Font stored as 5 columns of 7 bits
static const uint8_t _font5x7[][5] = {
    {0x00,0x00,0x00,0x00,0x00}, // ' '
    {0x00,0x00,0x5F,0x00,0x00}, // '!'
    {0x00,0x07,0x00,0x07,0x00}, // '"'
    {0x14,0x7F,0x14,0x7F,0x14}, // '#'
    {0x24,0x2A,0x7F,0x2A,0x12}, // '$'
    {0x23,0x13,0x08,0x64,0x62}, // '%'
    {0x36,0x49,0x55,0x22,0x50}, // '&'
    {0x00,0x05,0x03,0x00,0x00}, // '''
    {0x00,0x1C,0x22,0x41,0x00}, // '('
    {0x00,0x41,0x22,0x1C,0x00}, // ')'
    {0x14,0x08,0x3E,0x08,0x14}, // '*'
    {0x08,0x08,0x3E,0x08,0x08}, // '+'
    {0x00,0x50,0x30,0x00,0x00}, // ','
    {0x08,0x08,0x08,0x08,0x08}, // '-'
    {0x00,0x60,0x60,0x00,0x00}, // '.'
    {0x20,0x10,0x08,0x04,0x02}, // '/'
    {0x3E,0x51,0x49,0x45,0x3E}, // '0'
    {0x00,0x42,0x7F,0x40,0x00}, // '1'
    {0x42,0x61,0x51,0x49,0x46}, // '2'
    {0x21,0x41,0x45,0x4B,0x31}, // '3'
    {0x18,0x14,0x12,0x7F,0x10}, // '4'
    {0x27,0x45,0x45,0x45,0x39}, // '5'
    {0x3C,0x4A,0x49,0x49,0x30}, // '6'
    {0x01,0x71,0x09,0x05,0x03}, // '7'
    {0x36,0x49,0x49,0x49,0x36}, // '8'
    {0x06,0x49,0x49,0x29,0x1E}, // '9'
    {0x00,0x36,0x36,0x00,0x00}, // ':'
    {0x00,0x56,0x36,0x00,0x00}, // ';'
    {0x08,0x14,0x22,0x41,0x00}, // '<'
    {0x14,0x14,0x14,0x14,0x14}, // '='
    {0x00,0x41,0x22,0x14,0x08}, // '>'
    {0x02,0x01,0x51,0x09,0x06}, // '?'
    {0x32,0x49,0x79,0x41,0x3E}, // '@'
    {0x7E,0x11,0x11,0x11,0x7E}, // 'A'
    {0x7F,0x49,0x49,0x49,0x36}, // 'B'
    {0x3E,0x41,0x41,0x41,0x22}, // 'C'
    {0x7F,0x41,0x41,0x22,0x1C}, // 'D'
    {0x7F,0x49,0x49,0x49,0x41}, // 'E'
    {0x7F,0x09,0x09,0x09,0x01}, // 'F'
    {0x3E,0x41,0x49,0x49,0x7A}, // 'G'
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
};

// Draw char at tile-local y, scale 1 or 2
inline void tile_char(uint16_t x, uint16_t ty, char c, uint16_t fg, uint16_t bg, uint8_t scale=2) {
    if (c < 32 || c > 126) c = '?';
    const uint8_t* glyph = _font5x7[c - 32];
    for (int col = 0; col < 5; col++) {
        uint8_t bits = glyph[col];
        for (int row = 0; row < 7; row++) {
            uint16_t colour = (bits >> row) & 1 ? fg : bg;
            for (int sy = 0; sy < scale; sy++)
                for (int sx = 0; sx < scale; sx++)
                    tile_pixel(x + col*scale + sx, ty + row*scale + sy, colour);
        }
    }
}
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

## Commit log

2026-04-13 working note on waveshare pico-audio rev2.1 - CS4344 with INTERNAL clock
2026-04-13 multi - note control (no wheel emulation)
2026-04-16 working version with LCD and joystick button support
2026-04-17 included USB-HOST for midi devices on pin 6 and 7
2026-04-18 added vibrato, chorus, drive, better menu control
    [config.h, effects.h, lcd.cpp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]
2026-05-22 added pcb start
    [waveshare.kicad_pcb, waveshare.kicad_sch]
2026-07-25 added pcb for keyscan matrix
    [picokeymatrix.kicad_pcb, picokeymatrix.kicad_sch, waveshare.kicad_pcb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]
2026-10-02 working chorus, leslie, click, percussion - with new keymatrix button mapping
    [organ-panel-beam.stl, organ-standof.scad, picokeymatrix.kicad_pcb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]
